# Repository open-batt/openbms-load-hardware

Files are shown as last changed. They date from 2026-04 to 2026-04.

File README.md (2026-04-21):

# OpenBMS Load




**OpenBMS Load** is a hardware design of a resistive load used for battery discharging. Its main purpose is testing the battery management system (BMS) during charge and discharge cycles.

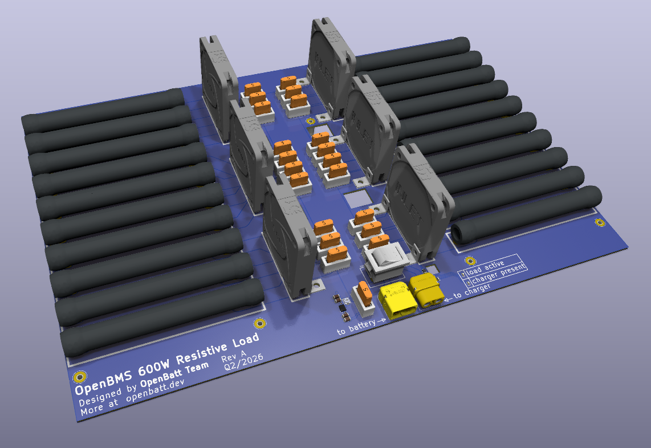
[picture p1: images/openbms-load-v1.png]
OpenBMS v3


## How OpenBMS Load fits into system?

Battery system consists of:

- Li-ion/Li-po battery - your custom 2 to 7-cell battery
- [OpenBMS](https://github.com/open-batt/openbms-hardware)
- Host - I2C/CAN interfaces, wake-up signal, can be a microcontroller, computer, etc.
- Load - your piece of equipment that draws energy from the battery. In this case, we provide OpenBMS-load-hardware, a 600W resistive load for easier BMS development and testing
- Charger - your custom charger, usually a CC/CV charger adjusted to your battery voltage and current

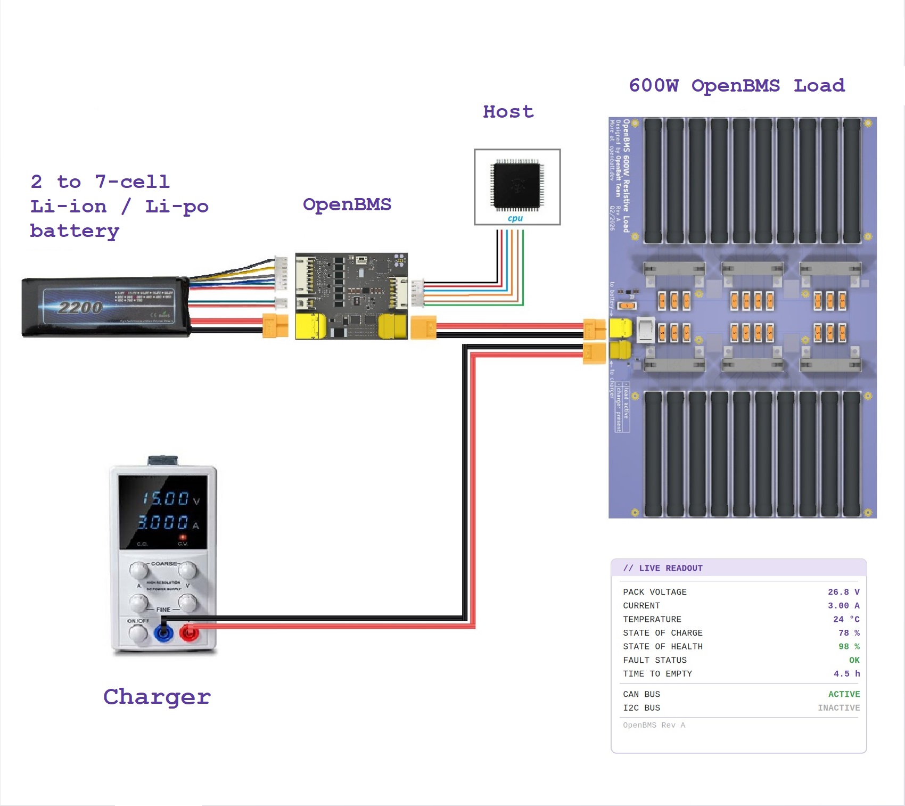
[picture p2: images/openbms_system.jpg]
OpenBMS v3

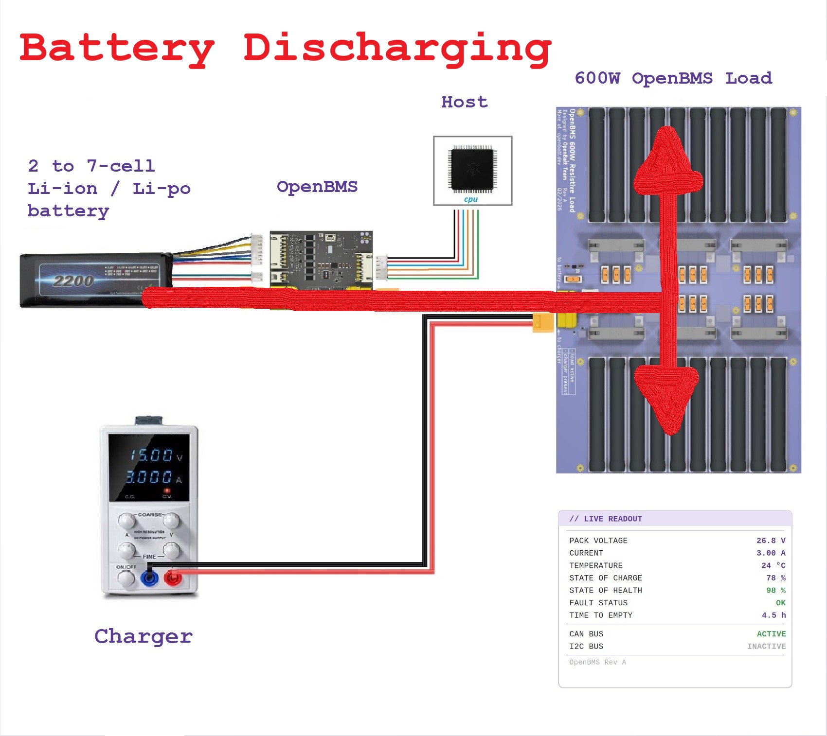
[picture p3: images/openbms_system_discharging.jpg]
OpenBMS v3

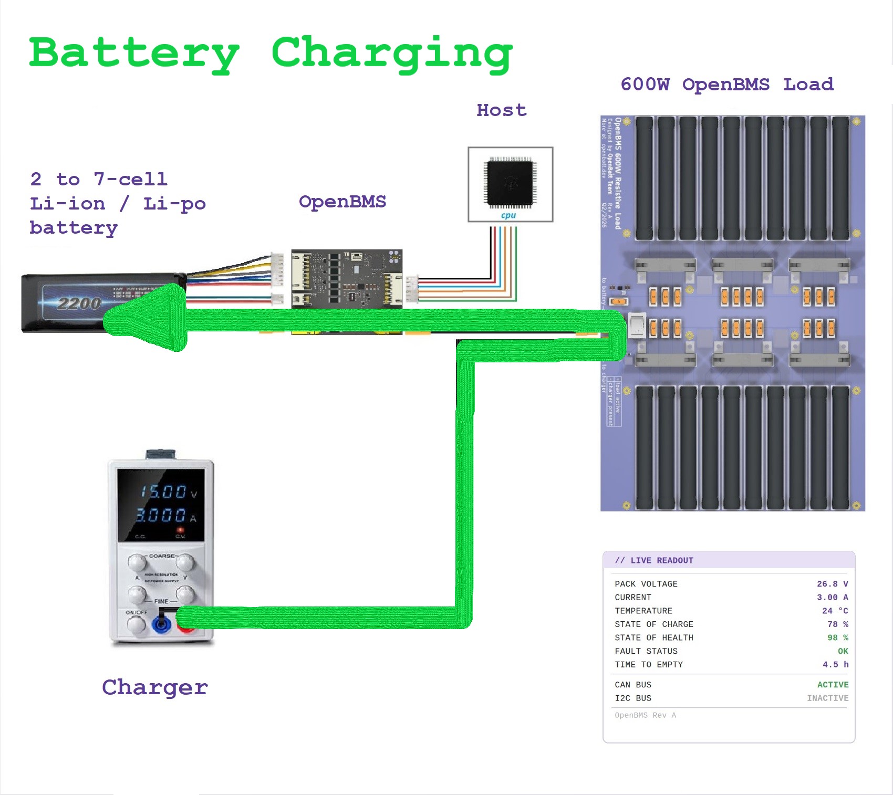
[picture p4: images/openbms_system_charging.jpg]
OpenBMS v3


## Features

- 🔥 Twenty 25-ohm 50W resistors to dissipate up to 600W
- 🔛  Jumpers / 5A fuse - each resistor has jumper/fuse to enable it or disable it - this way total load resistance can be adjusted from 1 to 20 ohms
- 🔌 Male XT60 connector for BMS (battery) connection
- 🔌 Female XT60 connector for charger connection
- 🔄 Tri state switch:
  - 1 - Battery discharging - energy flows from battery to load (resistors)
  - 2 - Battery charging - energy flows from charger to battery (resistors are bypassed and not used)
  - 3 - Idling - battery is neither charging nor discharging
- 💨 Six fans to blow heat from resistors - speed adjustable by potentiometer
- 🟢 Green LED to indicate that charger is present
- 🔴 Red LED to indicate that battery is discharging
  
## Overview

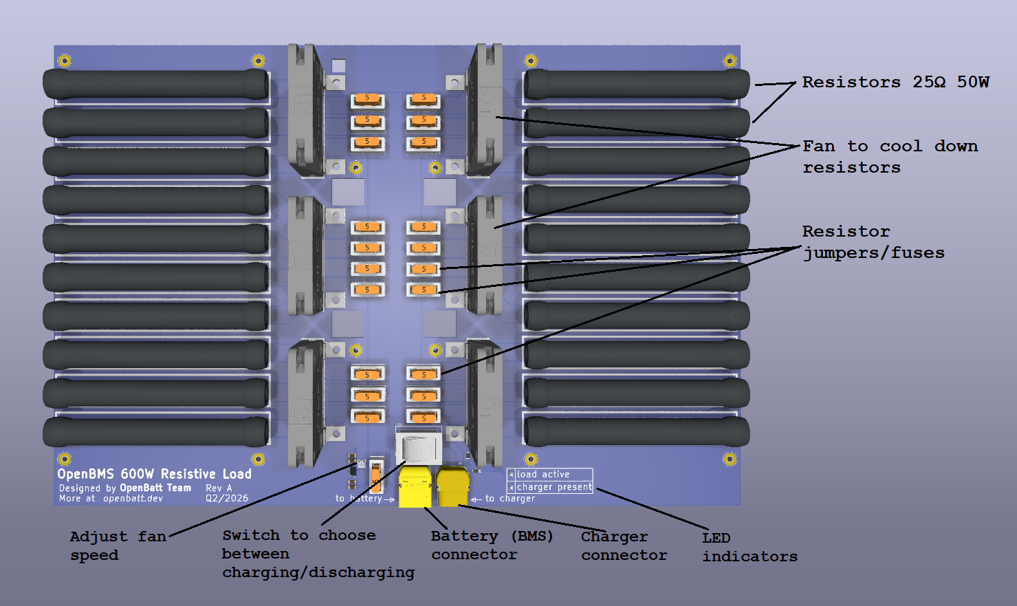
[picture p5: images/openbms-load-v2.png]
OpenBMS v3


The OpenBMS 600W Resistive Load is a purpose-built battery testing board designed to work alongside the OpenBMS system. 

It carries twenty 25Ω 50W wirewound resistors arranged across the board, capable of dissipating up to 600W of power. Each resistor is individually switchable via a jumper and protected by a 5A fuse, allowing the total load resistance to be adjusted between 1 and 20 ohms. 

Six cooling fans keep the resistors from overheating, with speed controlled by an onboard potentiometer. 

Two XT60 connectors handle battery and charger connections, and a three-position switch selects between discharging (energy flows from battery into the resistors), charging (charger feeds the battery directly, bypassing the resistors), and idle mode. 

A green LED signals charger presence and a red LED indicates active discharging.

## ❤️ Funding

This project is funded through [NGI0 Commons Fund](https://nlnet.nl/commonsfund), a fund established by [NLnet](https://nlnet.nl) with financial support from the European Commission's [Next Generation Internet](https://ngi.eu) program. 

[NLnet foundation logo](https://nlnet.nl)
[NGI Zero Logo](https://nlnet.nl/commonsfund)

We are very grateful to the NLnet team for helping us on our path, and we encourage you too to apply and get funds to build your project! 🚀
Learn more at the [NLnet project page](https://nlnet.nl/project/OpenBMS).

## License

OpenBMS-Load is licensed under CERN OHL-S v2 license.

Check [openbatt.dev](https://openbatt.dev) for more!

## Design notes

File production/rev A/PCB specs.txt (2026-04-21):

Layers: 2
PCB thickness: 1.6mm
Min hole size: 0.3mm
Surface finish:  HASL lead free
Min track/spacing:  6/6mil
Solder mask: purple
Silkscreen: white
Finished copper:  1 oz Cu

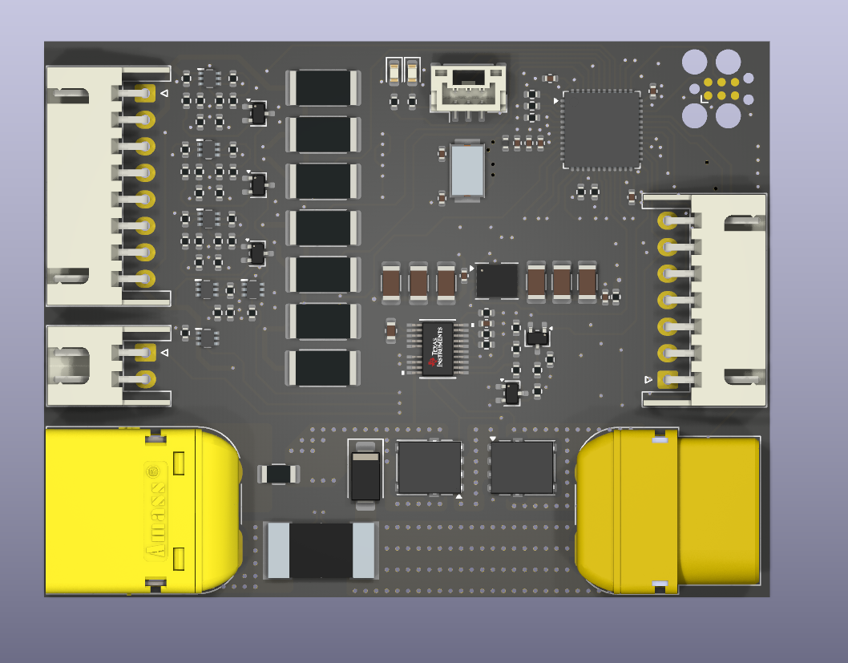
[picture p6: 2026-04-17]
images/openbms-v1.png

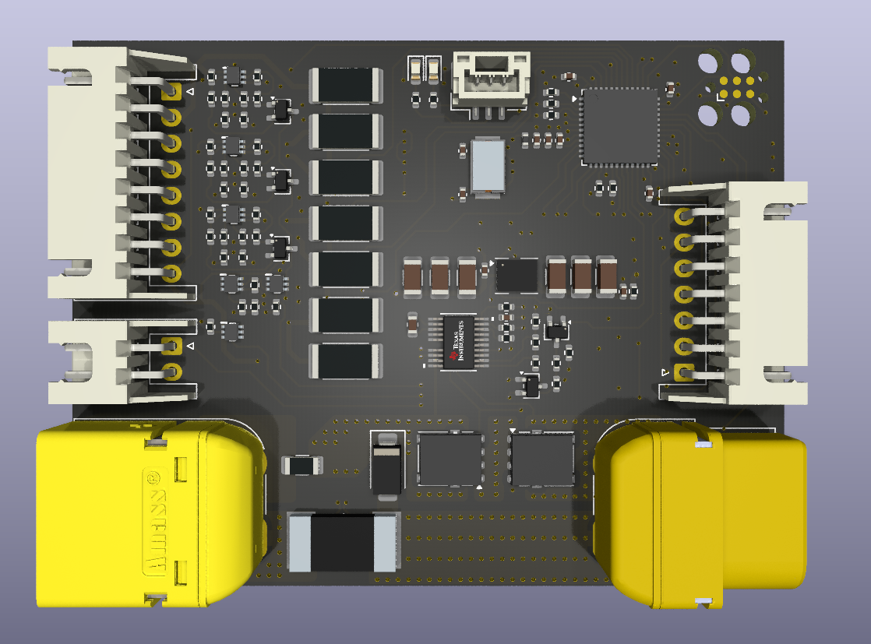
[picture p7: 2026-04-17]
images/openbms-v2.png

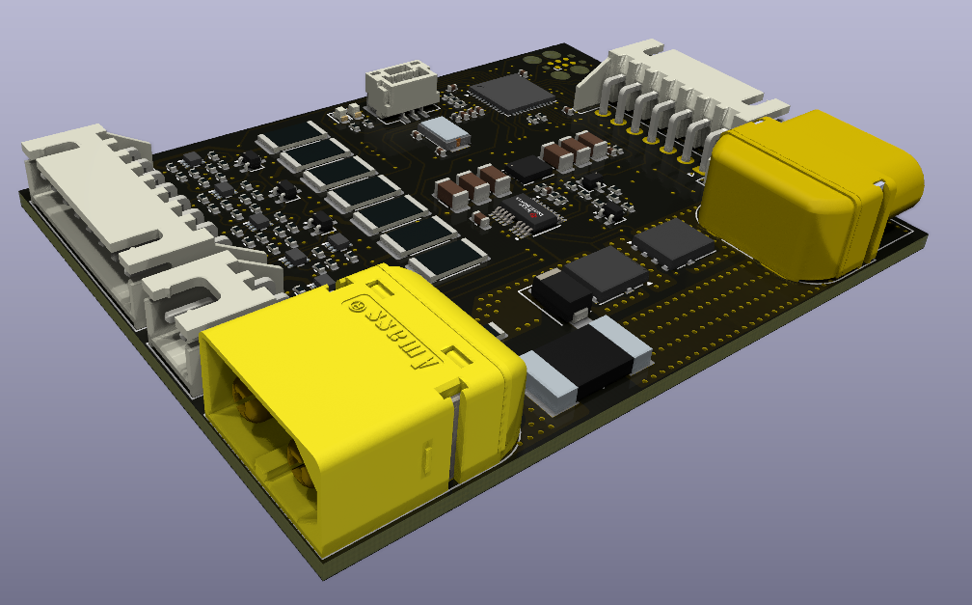
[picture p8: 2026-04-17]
images/openbms-v3.png

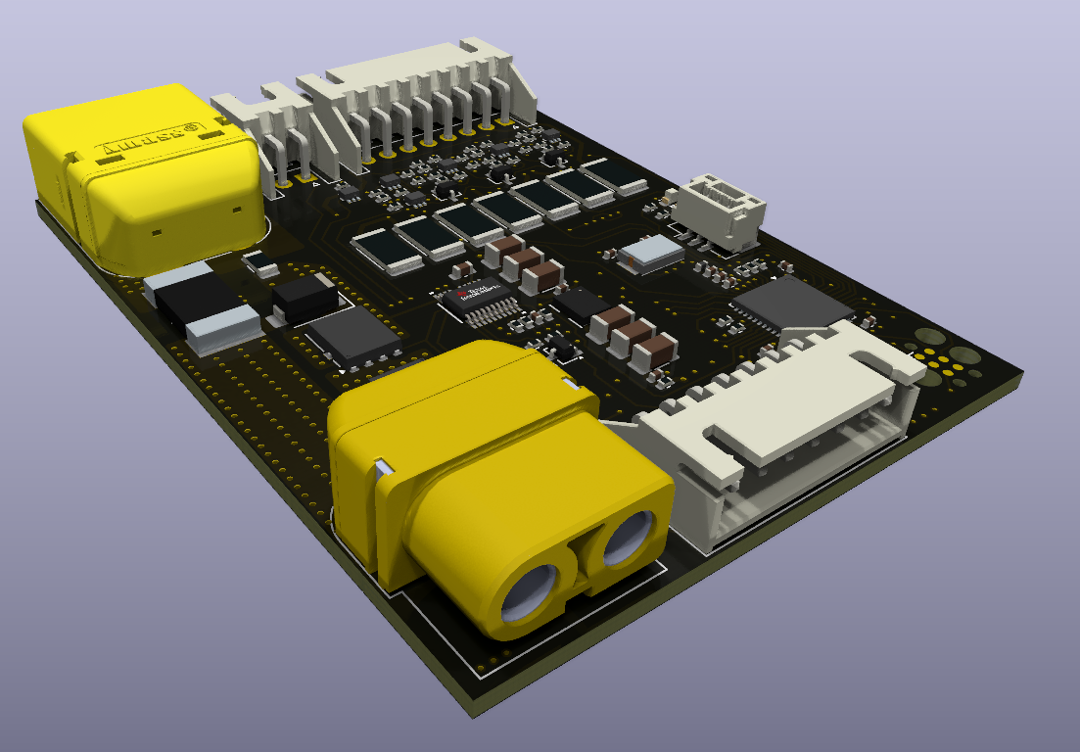
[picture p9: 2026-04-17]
images/openbms-v5.png

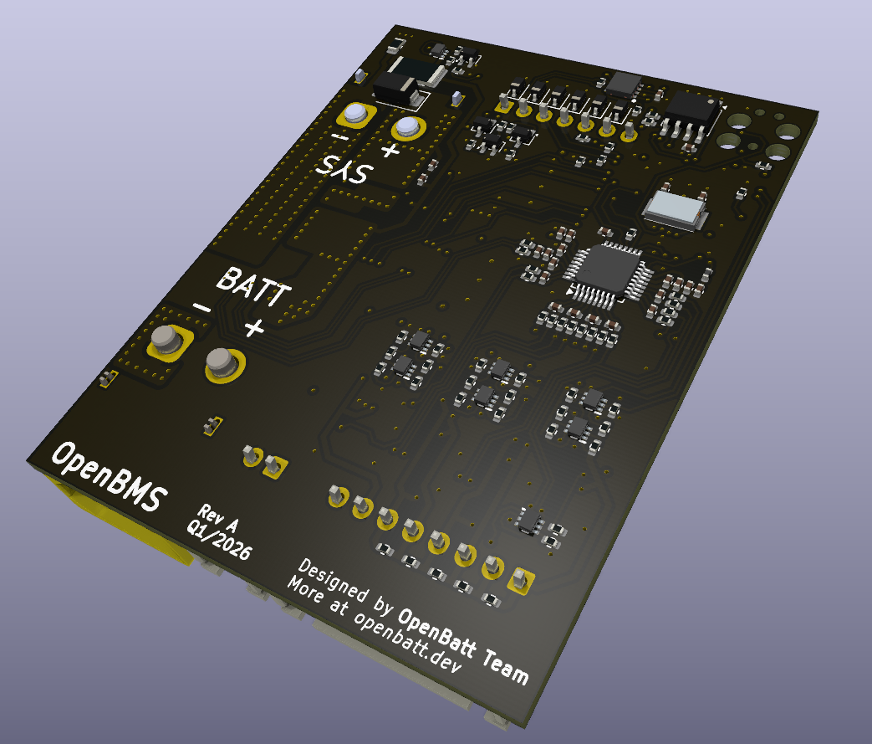
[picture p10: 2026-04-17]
images/openbms-v4.png

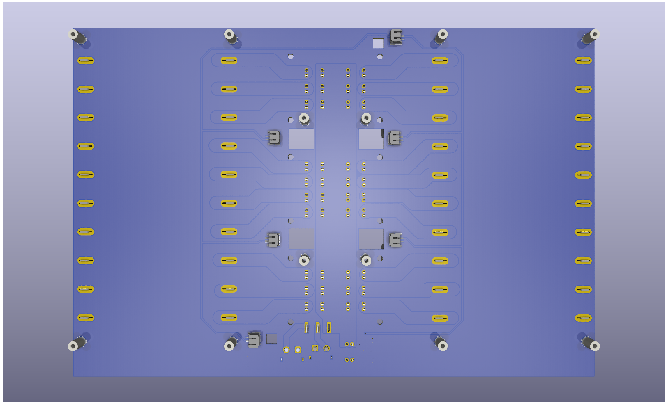
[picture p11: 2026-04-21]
production/rev A/openbms-load-img-3.png

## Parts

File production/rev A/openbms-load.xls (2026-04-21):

Reference | Qty | Value | Package | Manufacturer_Part_Number
B1,B2,B3,B4,B5,B6,B7,B8,B9,B10,B11,B12 | 12 | L mounting bracket | L bracket | 633
C1,C2,C4,C5 | 4 | 10u | 1206 | CL31A106MBHNNNE
C3,C6 | 2 | 100n | 0402 | GRM155R71A104KA01D
D1 | 1 | Green LED | 0603 | LTST-S270KGKT
D2 | 1 | Red LED | 0603 | LTST-C190KRKT
D3,D4 | 2 | LED driver | PowerDIâ 123 | AL5809-15P1-7
F1,F2,F3,F4,F5,F6,F7,F8,F9,F10,F11,F12,F13,F14,F15,F16,F17,F18,F19,F20,F21 | 21 | Fuse housing | 11x3.85mm | 3568
H1,H2,H3,H4,H5,H6,H7,H8,H9,H10,H11,H12 | 12 | Standoff M3 10mm | M3 10mm | 24433
J1,J2,J3,J4,J5,J6,J7,J8,J9,J10,J11,J12,J13,J14,J15,J16,J17,J18,J19,J20,J21 | 21 | 5A Fuse | 11x5mm | 0297005.WXNV
M1,M2,M3,M4,M5,M6 | 6 | Fan 50mm | 50x50x10mm | MF50101V1-1000U-A99
P1,P2,P3,P4,P5,P6 | 6 | JST connector | JST 02 connector | S2B-PH-SM4-TB
P7 | 1 | XT60PW-M connector | XT60PW-M connector | XT60PW-M
P8 | 1 | XT60PW-F connector | XT60PW-F connector | XT60PW-F
POT1 | 1 | 10k pot | 3.8x3.6mm | TC33X-2-103E
R1,R2,R3,R4,R5,R6,R7,R8,R9,R10,R11,R12,R13,R14,R15,R16,R17,R18,R19,R20 | 20 | 25R 50W | 102x15 | L50J25RE
SW1 | 1 | Switch | 19.2x12.9mm | VRS-3-Q3PSI-19KNN-0-M2
U1 | 1 | LMZM23600SILR | 3.8 x 3 | LMZM23600SILR

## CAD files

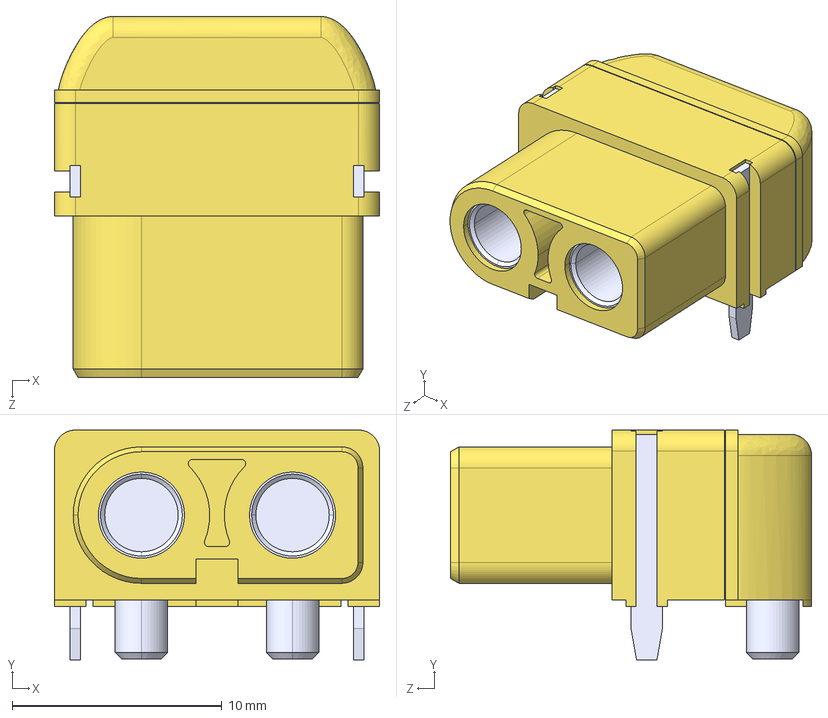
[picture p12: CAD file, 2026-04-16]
openbms-load/3D models/XT60PW-F.stp
15.5 x 11.0 x 17.2 mm

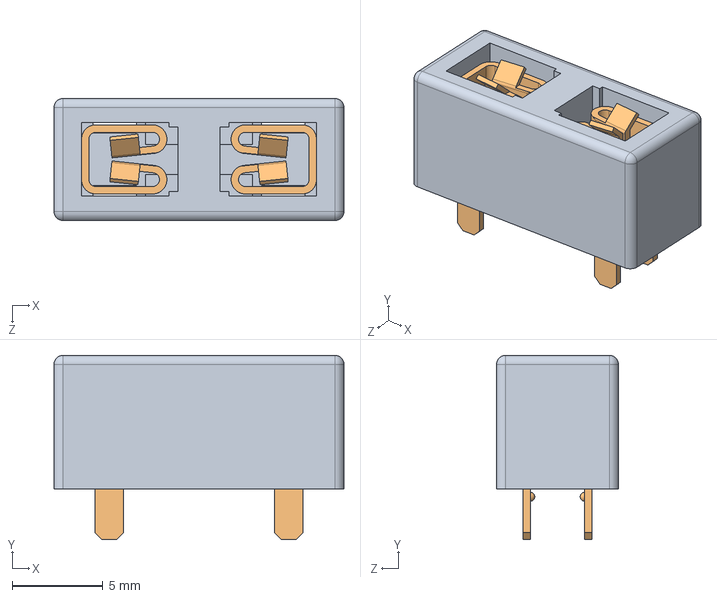
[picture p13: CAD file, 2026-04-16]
openbms-load/3D models/3568.stp
16.0 x 10.2 x 6.73 mm

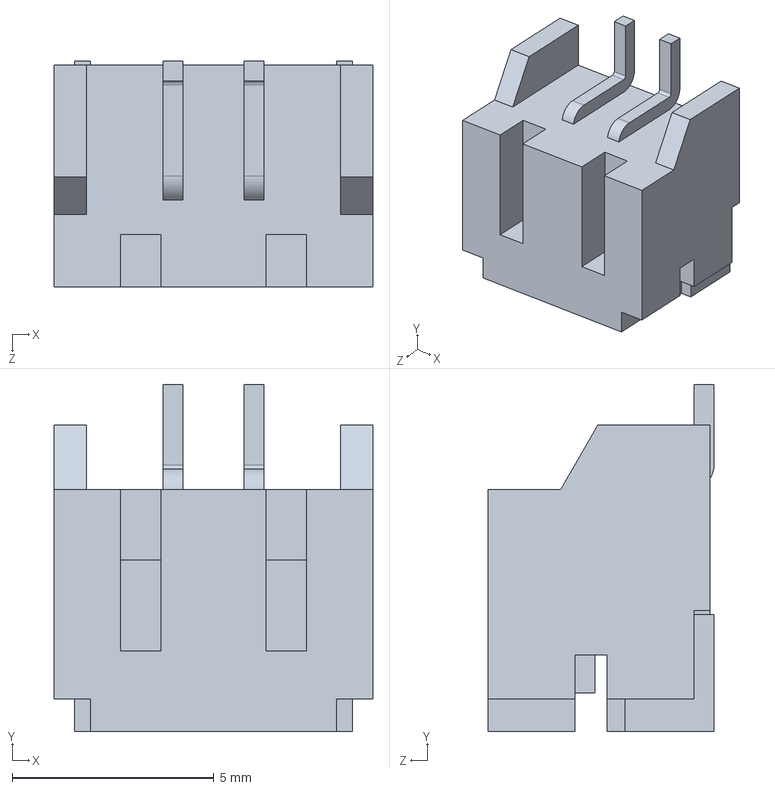
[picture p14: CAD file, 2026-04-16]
openbms-load/3D models/S2B-PH-SM4-TB_LF__SN_.stp
7.90 x 8.60 x 5.60 mm

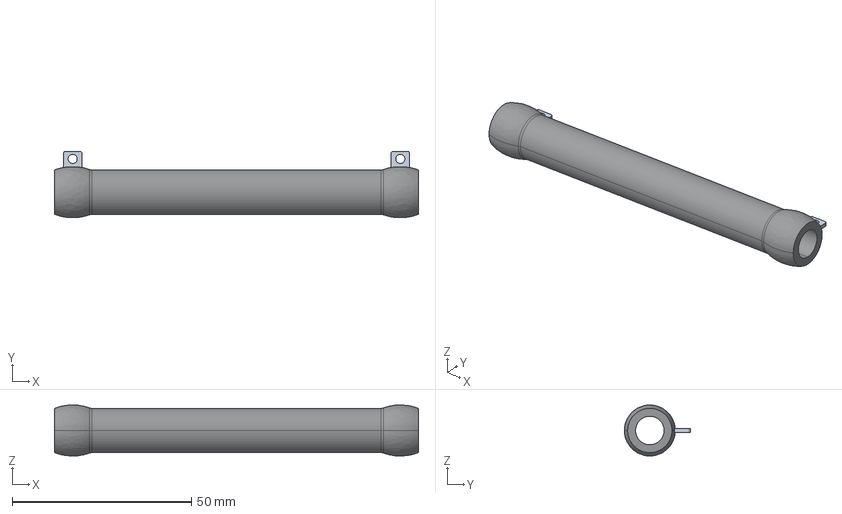
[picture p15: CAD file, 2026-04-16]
openbms-load/3D models/L50J25RE.stp
101.6 x 18.6 x 14.2 mm

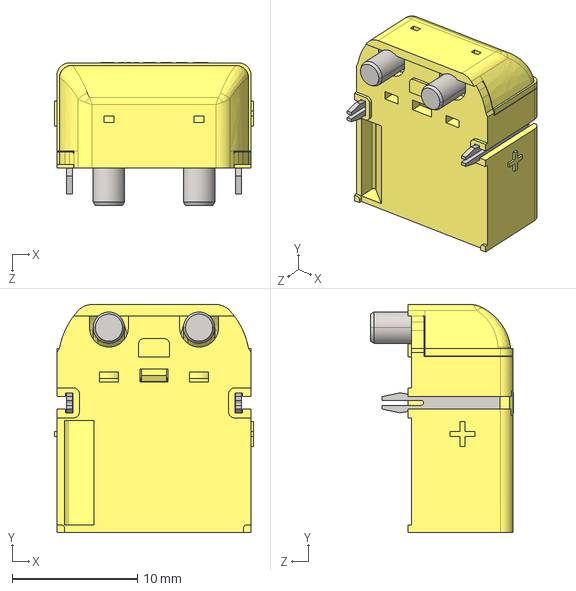
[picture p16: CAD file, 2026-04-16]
openbms-load/3D models/XT60PW-M.stp
15.9 x 18.2 x 11.5 mm

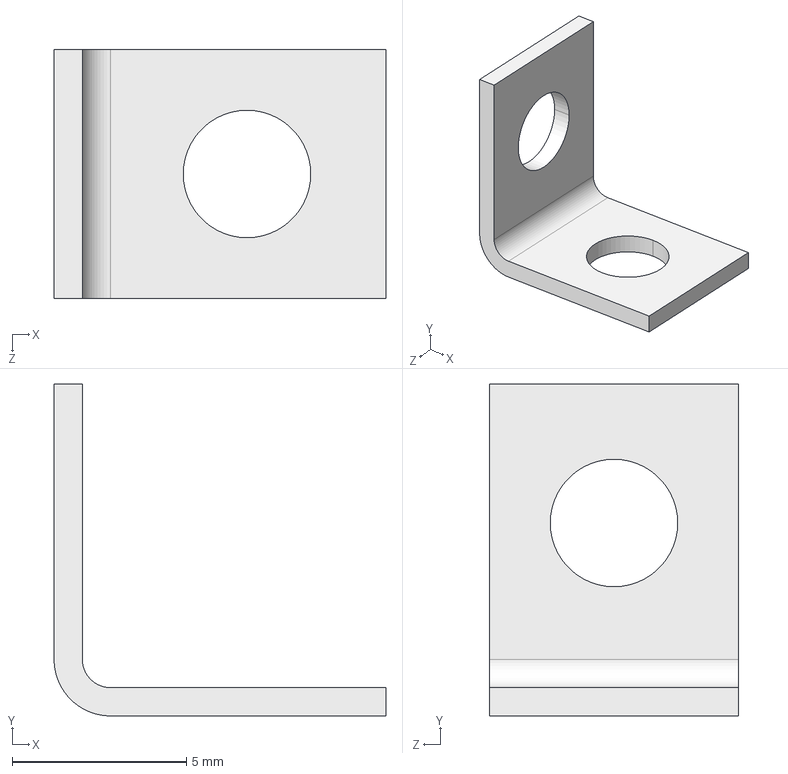
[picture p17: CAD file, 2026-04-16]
openbms-load/3D models/633.stp
9.53 x 9.53 x 7.14 mm

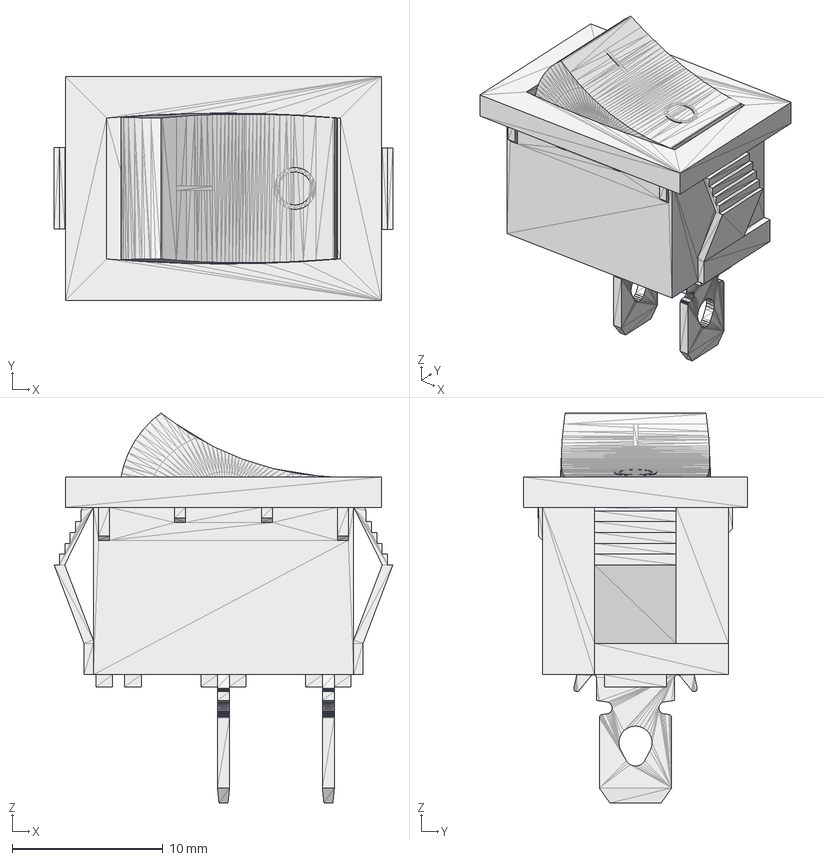
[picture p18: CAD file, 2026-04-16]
openbms-load/3D models/VRS-3-Q3PSI-19KNN-0-M2.step
22.5 x 14.8 x 25.8 mm

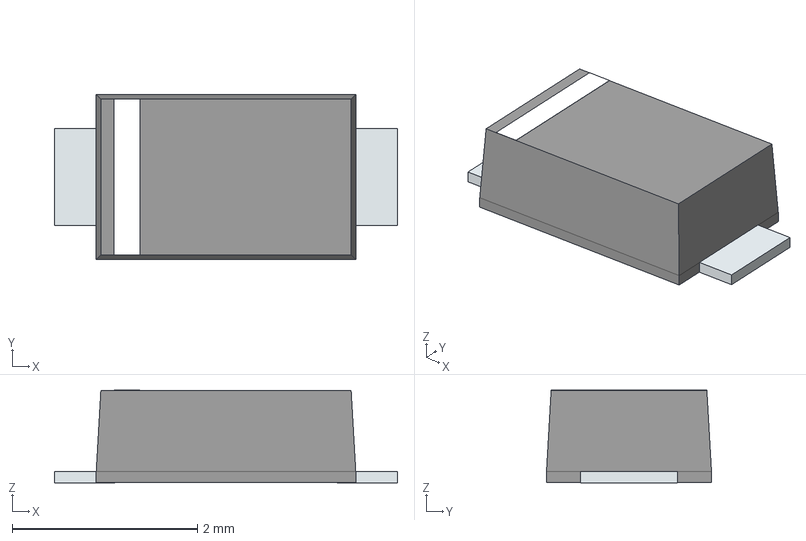
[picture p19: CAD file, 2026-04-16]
openbms-load/3D models/AL5809-15P1-7.stp
3.70 x 1.78 x 1.00 mm
PinKIdent
PinK
PinA

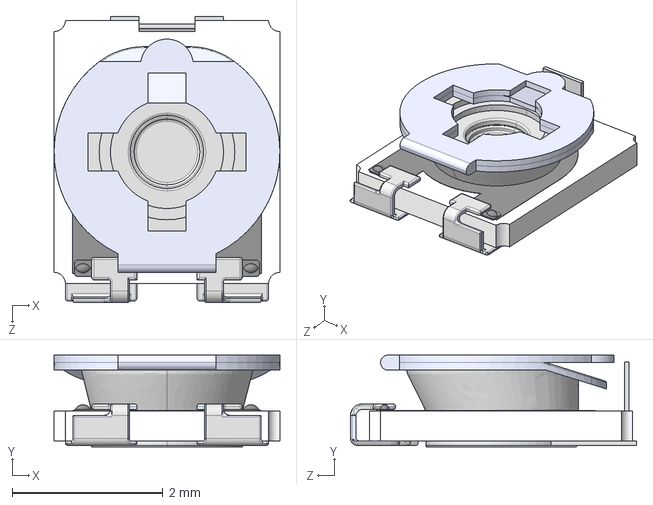
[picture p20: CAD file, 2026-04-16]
openbms-load/3D models/TC33X-2-103E.stp
3.00 x 1.22 x 3.80 mm

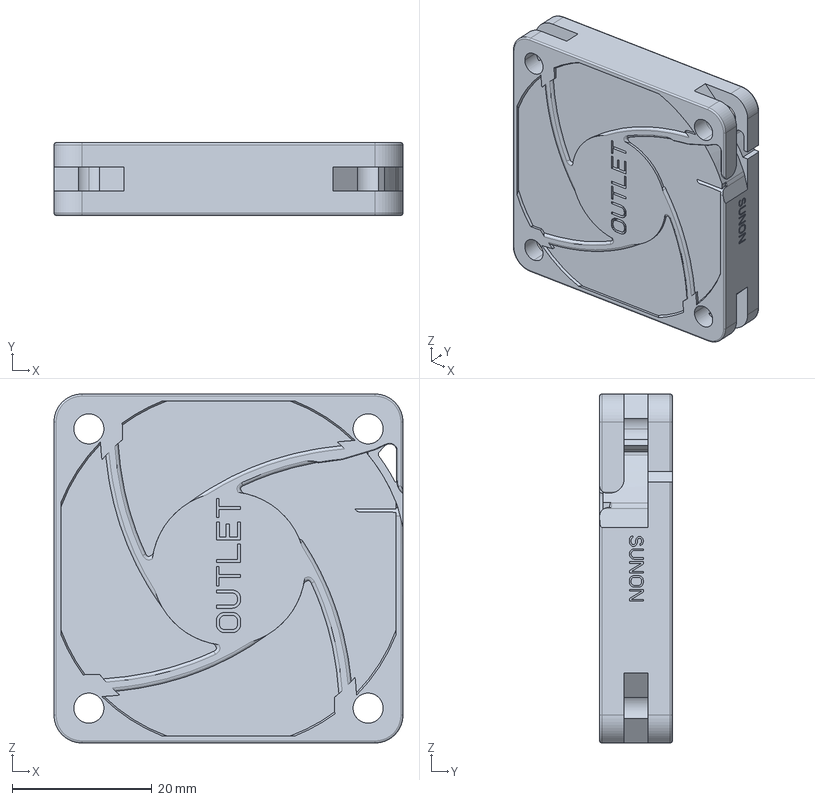
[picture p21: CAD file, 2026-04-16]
openbms-load/3D models/MF50101V1-1000U-A99.stp
50.0 x 10.4 x 50.0 mm

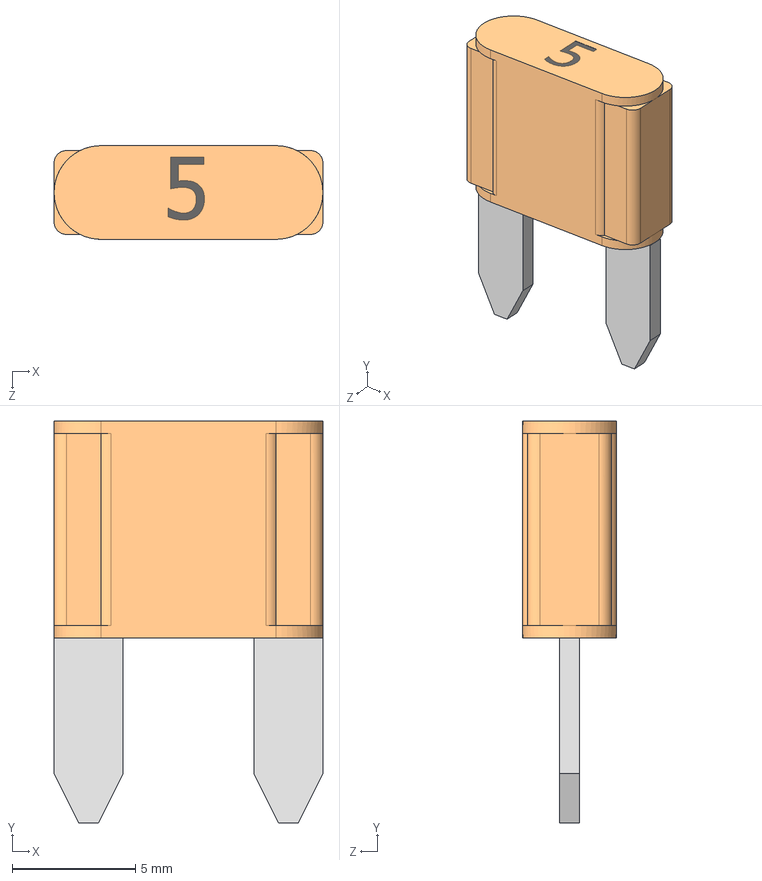
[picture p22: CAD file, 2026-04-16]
openbms-load/3D models/0297005.WXNV.stp
10.9 x 16.3 x 3.80 mm
Part8fgfgfg
edeedqq
edeedqq_MIR

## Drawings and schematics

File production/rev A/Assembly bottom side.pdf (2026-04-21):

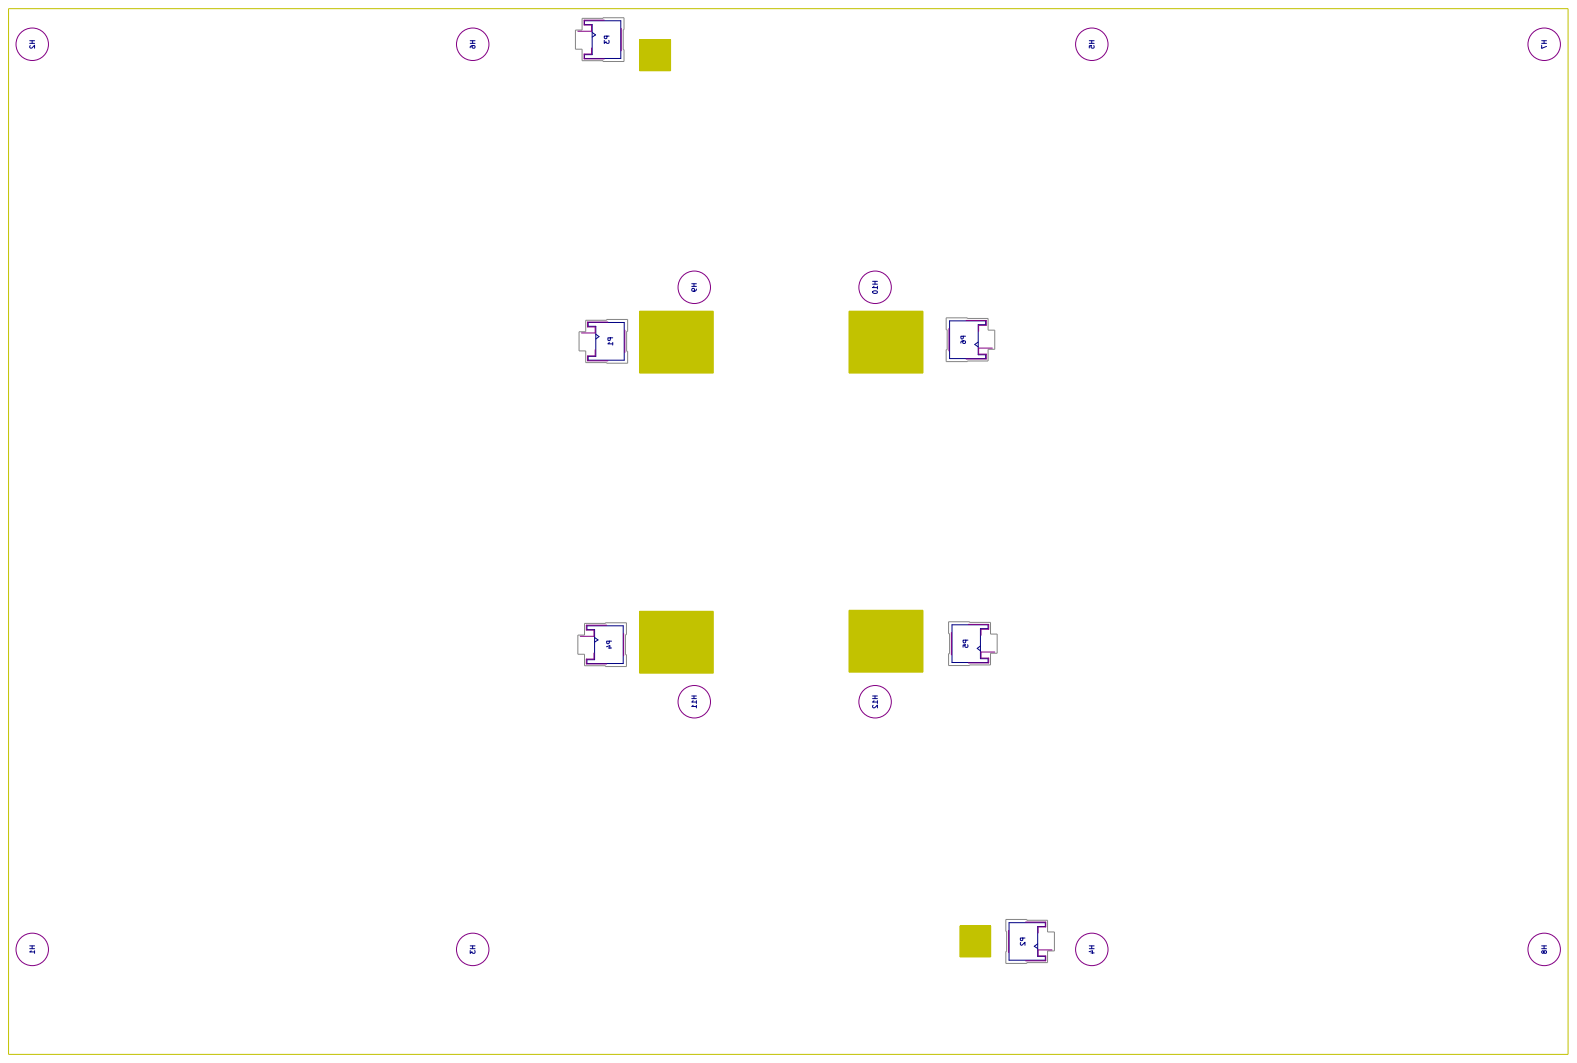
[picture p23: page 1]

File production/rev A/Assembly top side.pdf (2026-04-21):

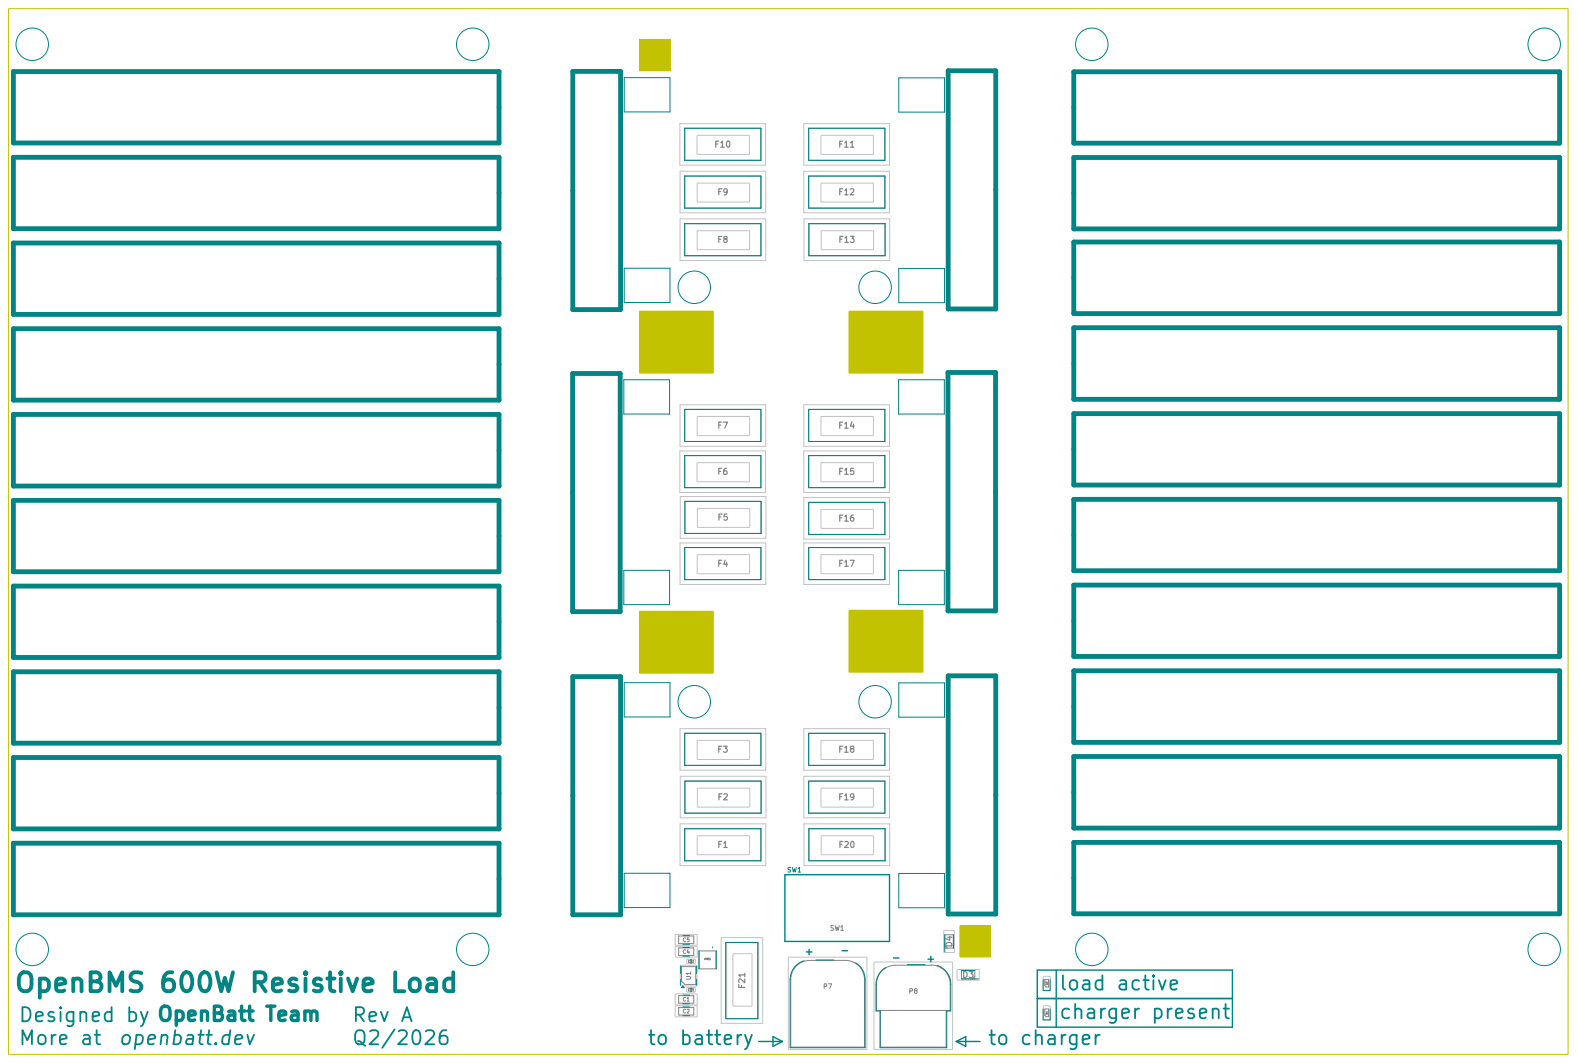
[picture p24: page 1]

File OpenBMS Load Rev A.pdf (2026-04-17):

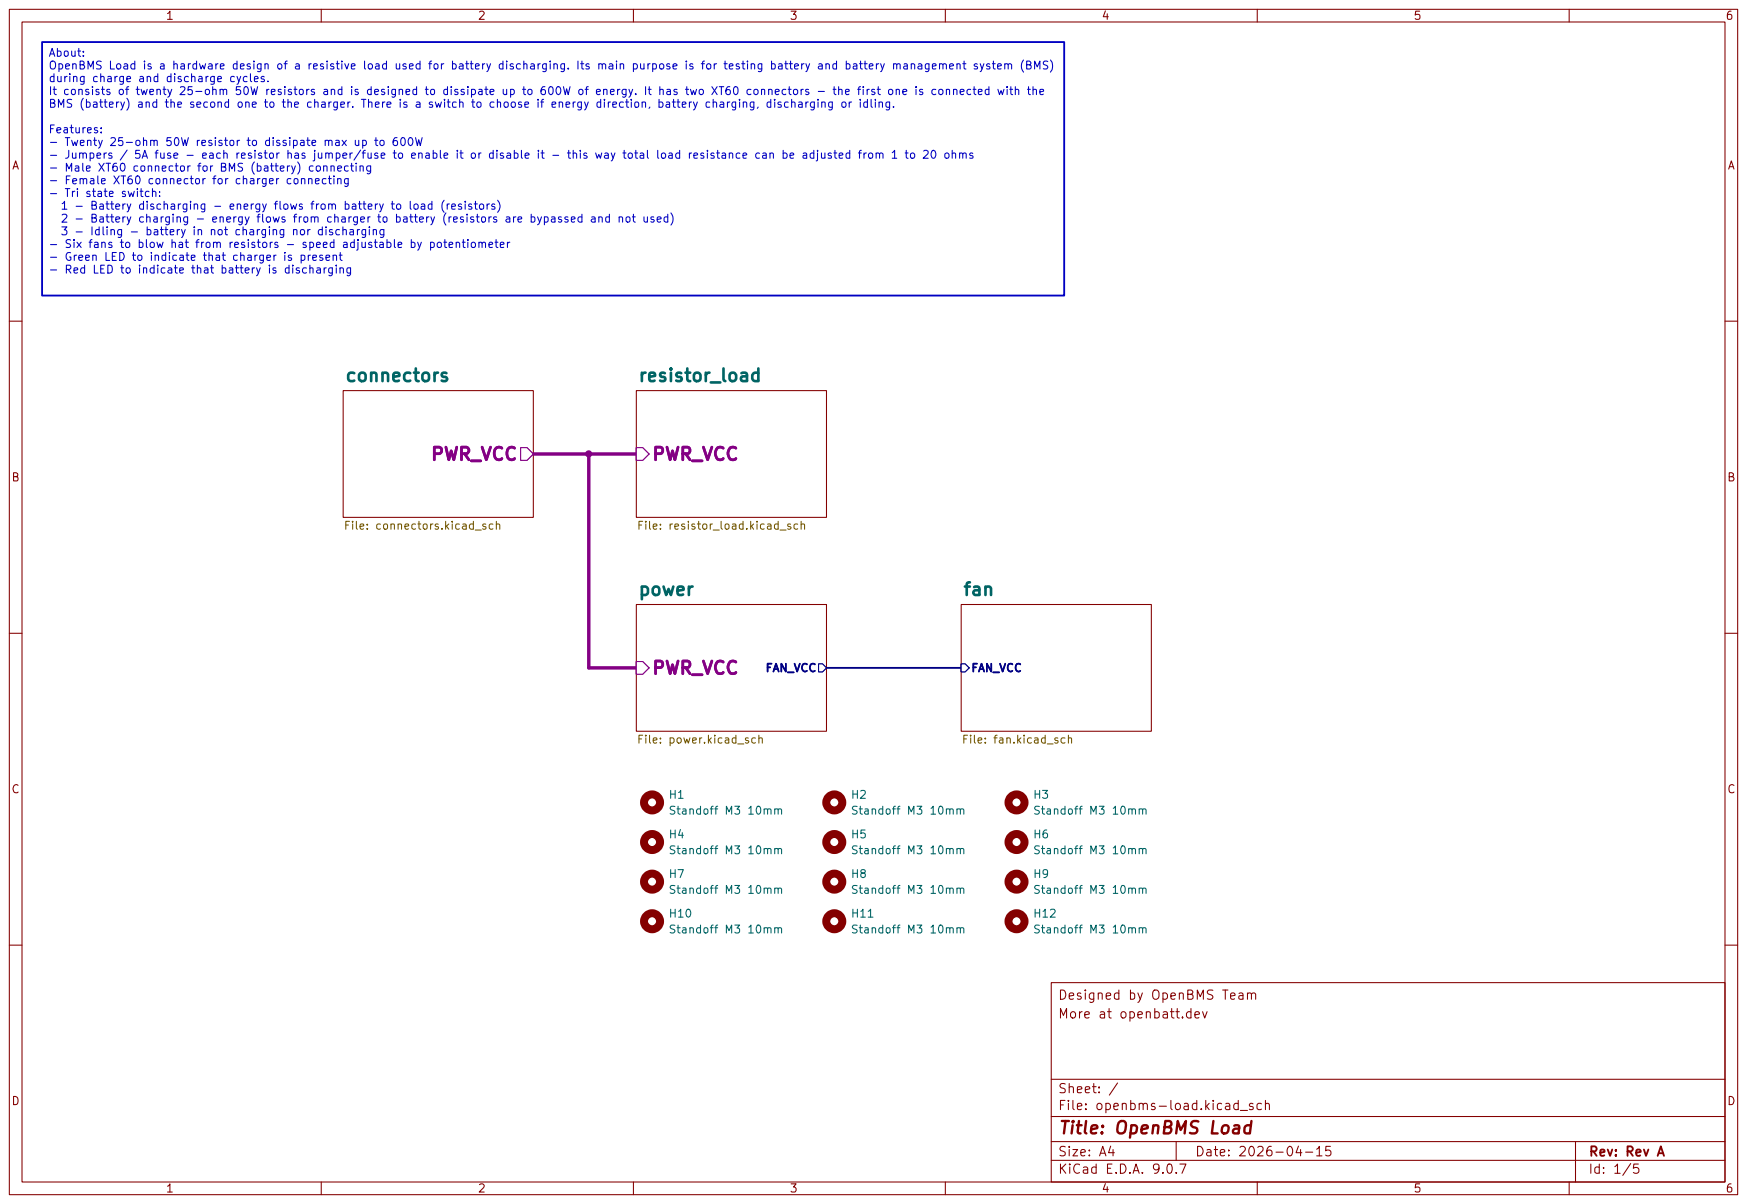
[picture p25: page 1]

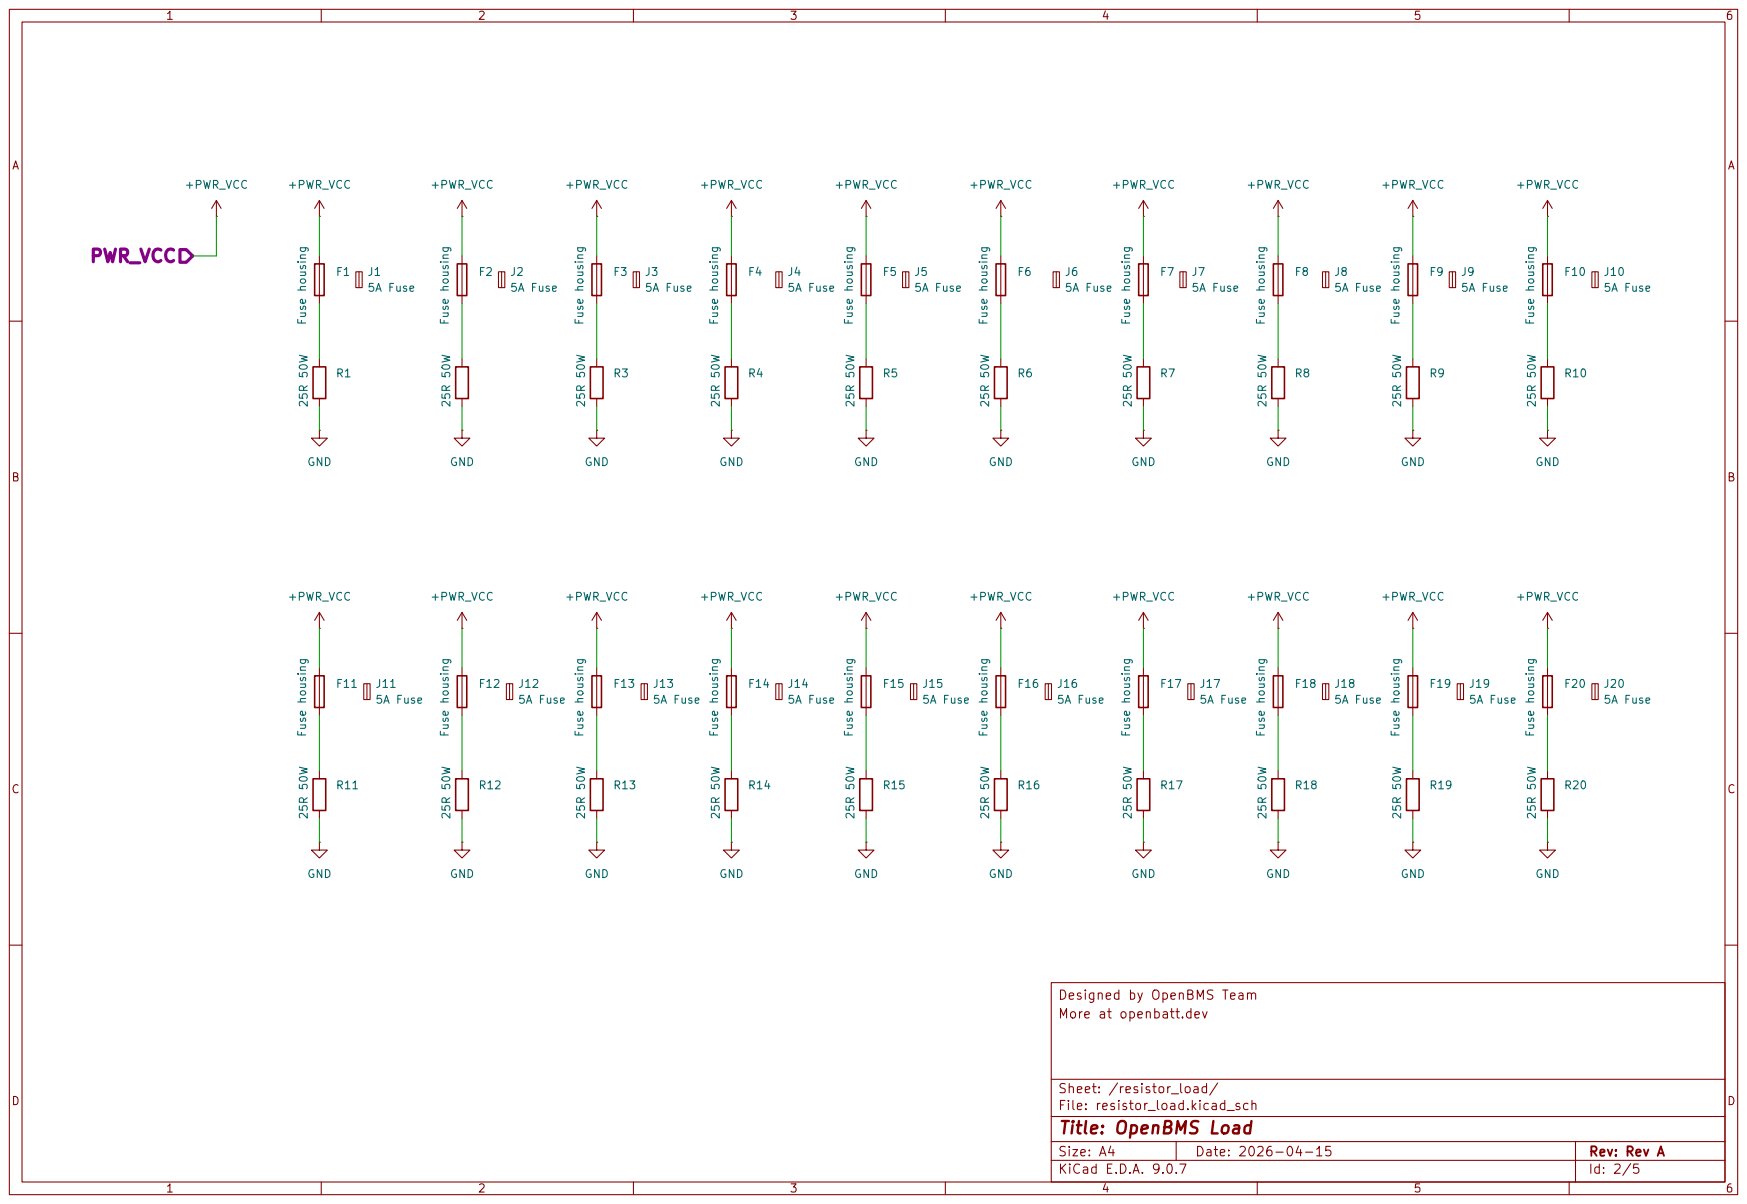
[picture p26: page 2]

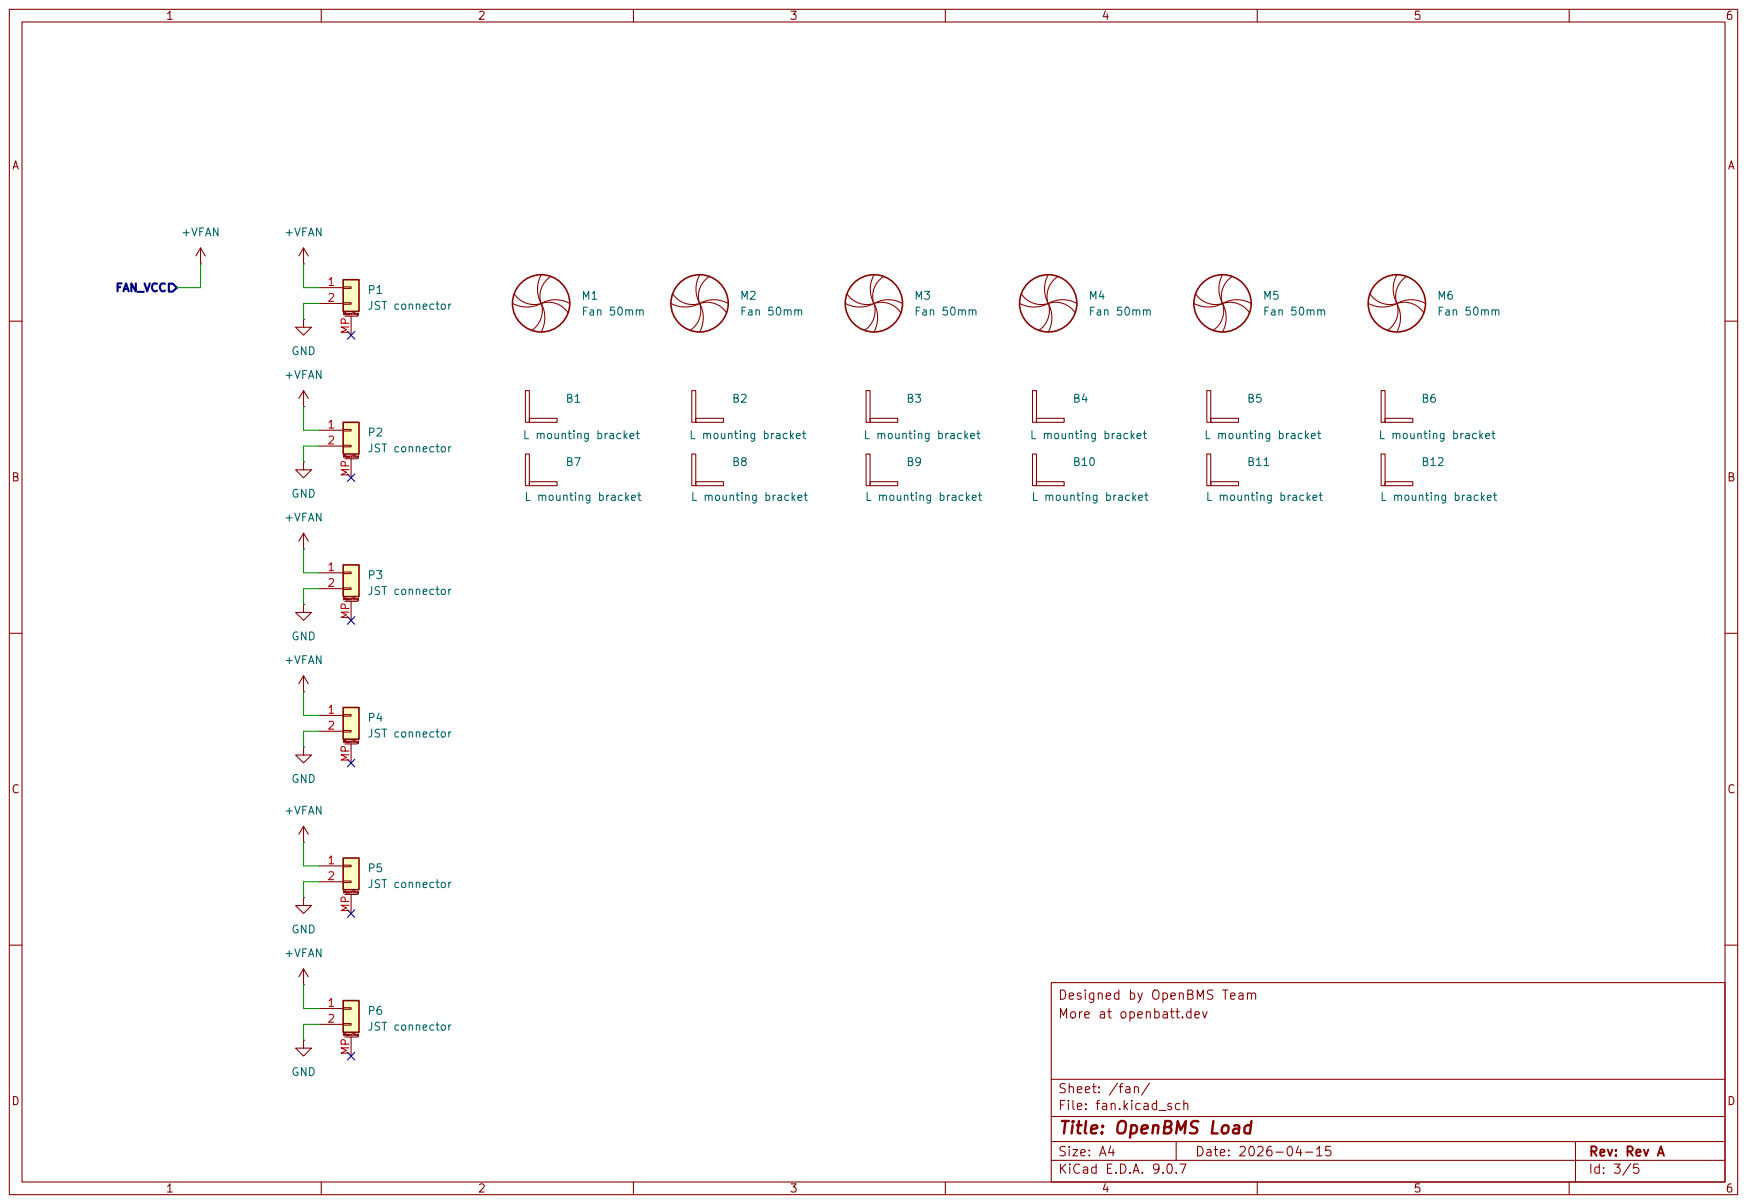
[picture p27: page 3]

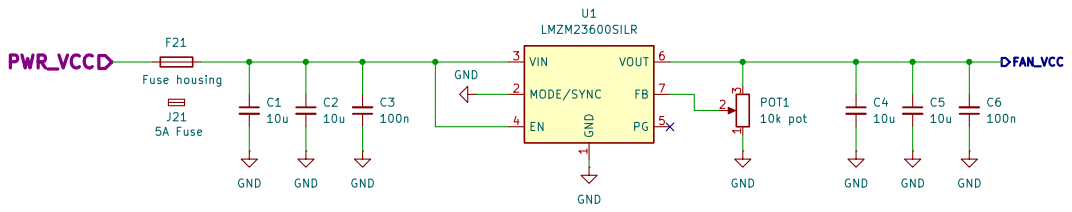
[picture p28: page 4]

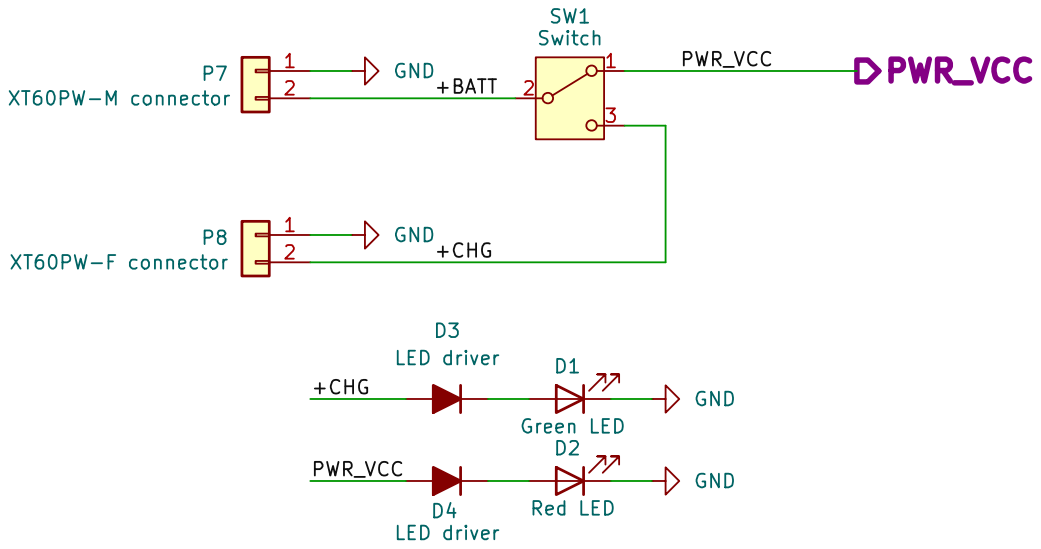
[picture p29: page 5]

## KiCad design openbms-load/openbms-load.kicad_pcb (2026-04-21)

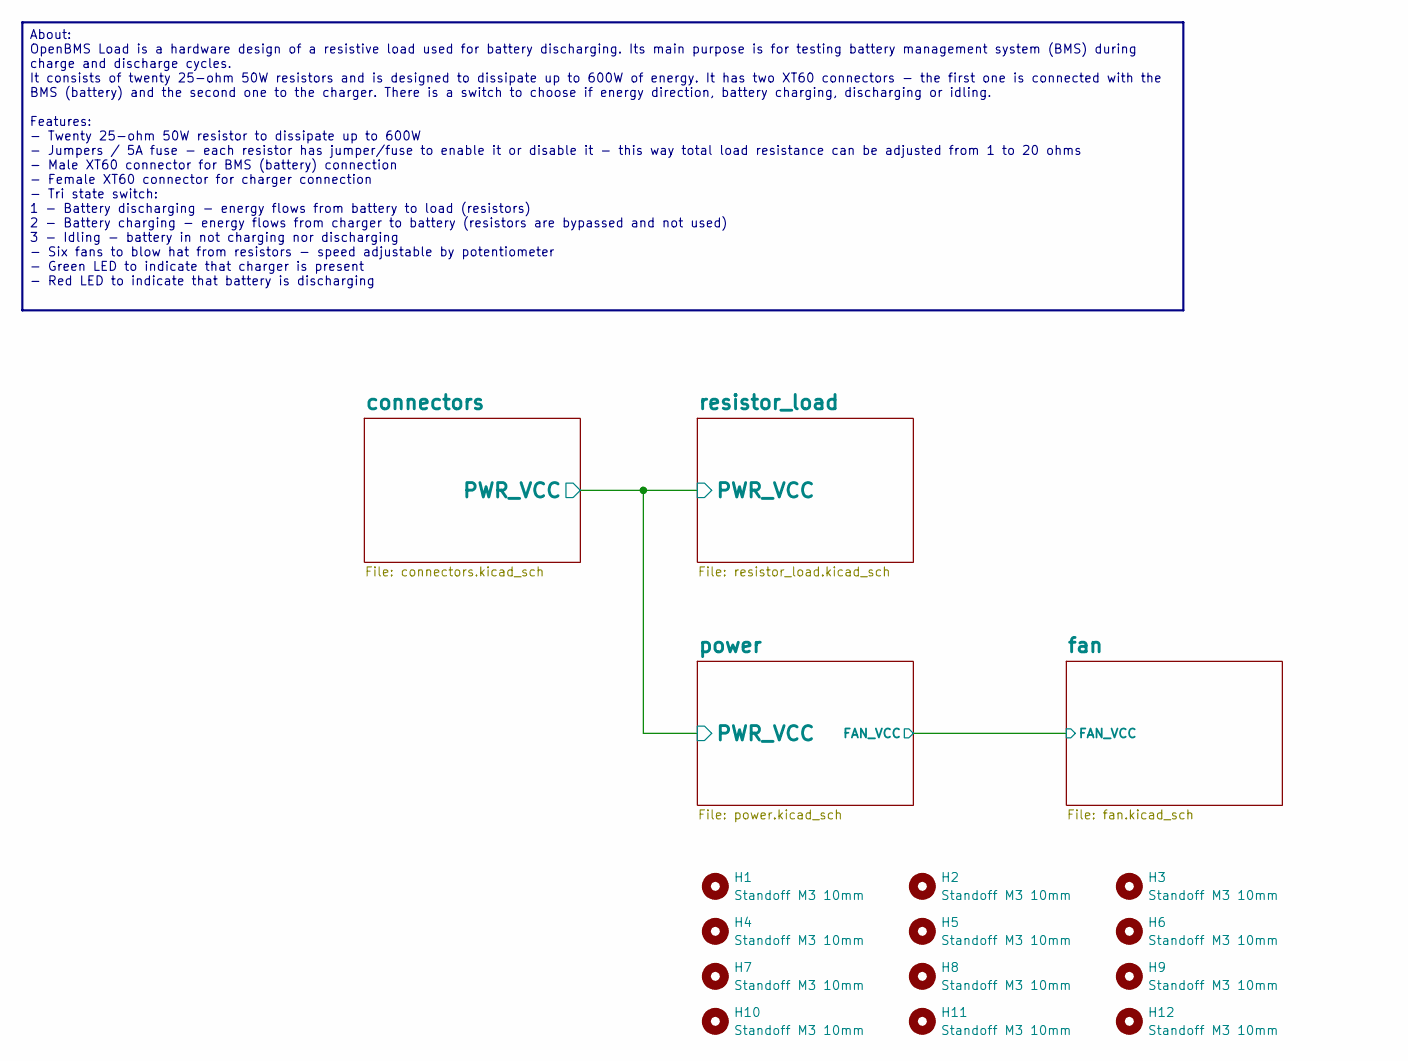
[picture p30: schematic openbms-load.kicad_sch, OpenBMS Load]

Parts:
H1, H2, H3, H4, H5, H6, H7, H8, H9, H10, H11, H12: Standoff M3 10mm; 24433; Manufacturer_Part_Number 24433

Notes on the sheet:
About: OpenBMS Load is a hardware design of a resistive load used for battery discharging. Its main purpose is for testing battery management system (BMS) during charge and discharge cycles. It consists of twenty 25-ohm 50W resistors and is designed to dissipate up to 600W of energy. It has two XT6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

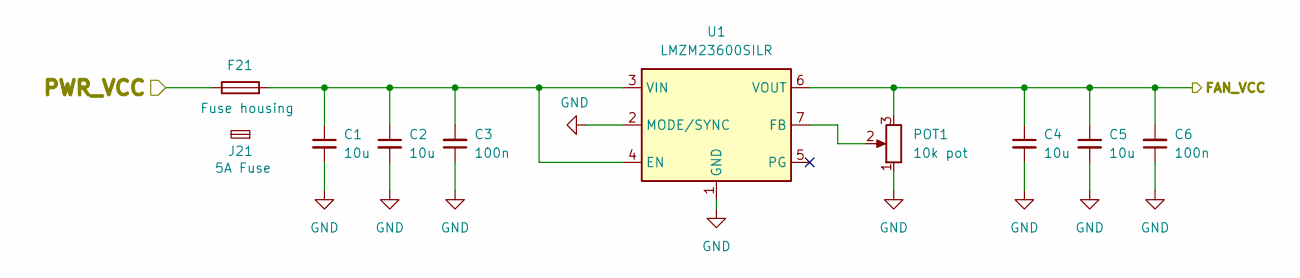
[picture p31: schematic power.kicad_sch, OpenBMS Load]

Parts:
C1, C2, C4, C5: 10u; C_1206_3216Metric; Manufacturer_Part_Number CL31A106MBHNNNE
C3, C6: 100n; C_0402_1005Metric; Manufacturer_Part_Number GRM155R71A104KA01D
F21: Fuse housing; 3568; Manufacturer_Part_Number 3568
J21: 5A Fuse; 0297005.WXNV; Manufacturer_Part_Number 0297005.WXNV
POT1: 10k pot; TC33X2503E; Manufacturer_Part_Number TC33X-2-103E
U1: LMZM23600SILR; Manufacturer_Part_Number LMZM23600SILR

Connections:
+PWR_VCC: F21.1; also elsewhere on the board
+VFAN: C4.1, C5.1, C6.2, POT1.3, U1.6 (VOUT); also elsewhere on the board
GND: C1.2, C2.2, C3.1, C4.2, C5.2, C6.1, POT1.1, U1.1 (GND), U1.2 (MODE/SYNC), U1.11 (GND); also elsewhere on the board
unnamed: C1.1, C2.1, C3.2, F21.2, U1.3 (VIN), U1.4 (EN)
unnamed: POT1.2, U1.7 (FB)

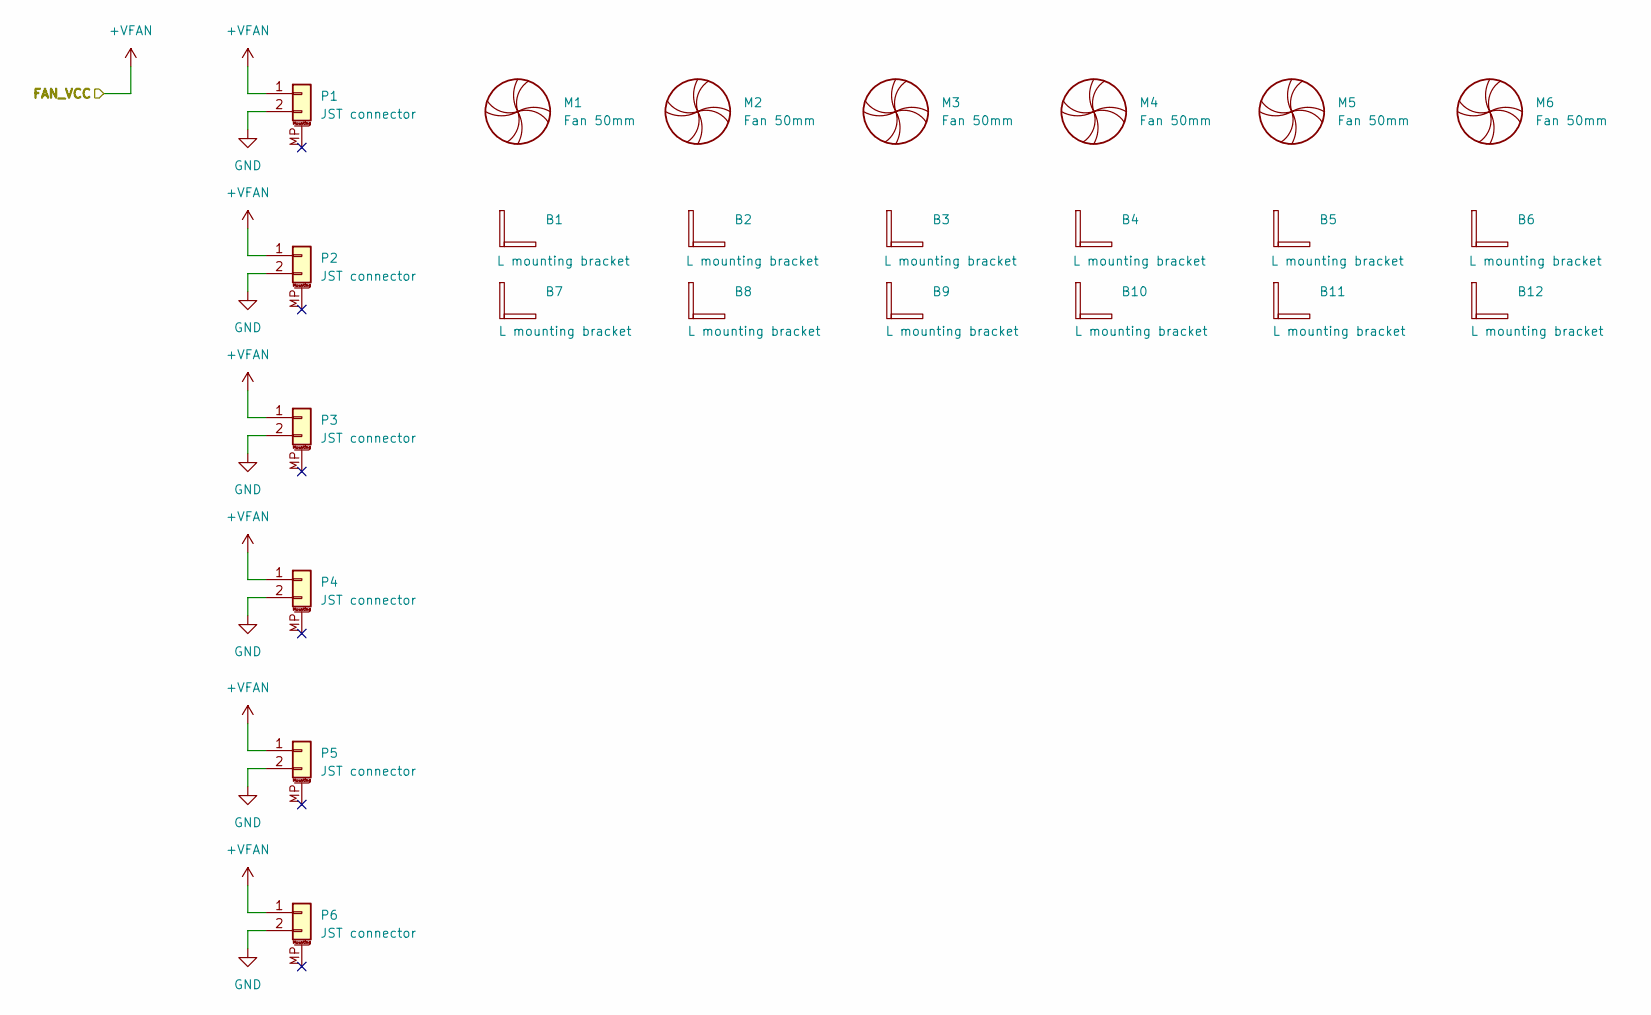
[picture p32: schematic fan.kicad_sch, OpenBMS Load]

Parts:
B1, B2, B3, B4, B5, B6, B7, B8, B9, B10, B11, B12: L mounting bracket; 633; Manufacturer_Part_Number 633
M1, M2, M3, M4, M5, M6: Fan 50mm; fan_MF50101V1-1000U-A99; Manufacturer_Part_Number MF50101V1-1000U-A99
P1, P2, P3, P4, P5, P6: JST connector; JST_PH_S2B-PH-SM4-TB_1x02-1MP_P2.00mm_Horizontal; Manufacturer_Part_Number S2B-PH-SM4-TB

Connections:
+VFAN: P1.1, P2.1, P3.1, P4.1, P5.1, P6.1; also elsewhere on the board
GND: P1.2, P2.2, P3.2, P4.2, P5.2, P6.2; also elsewhere on the board

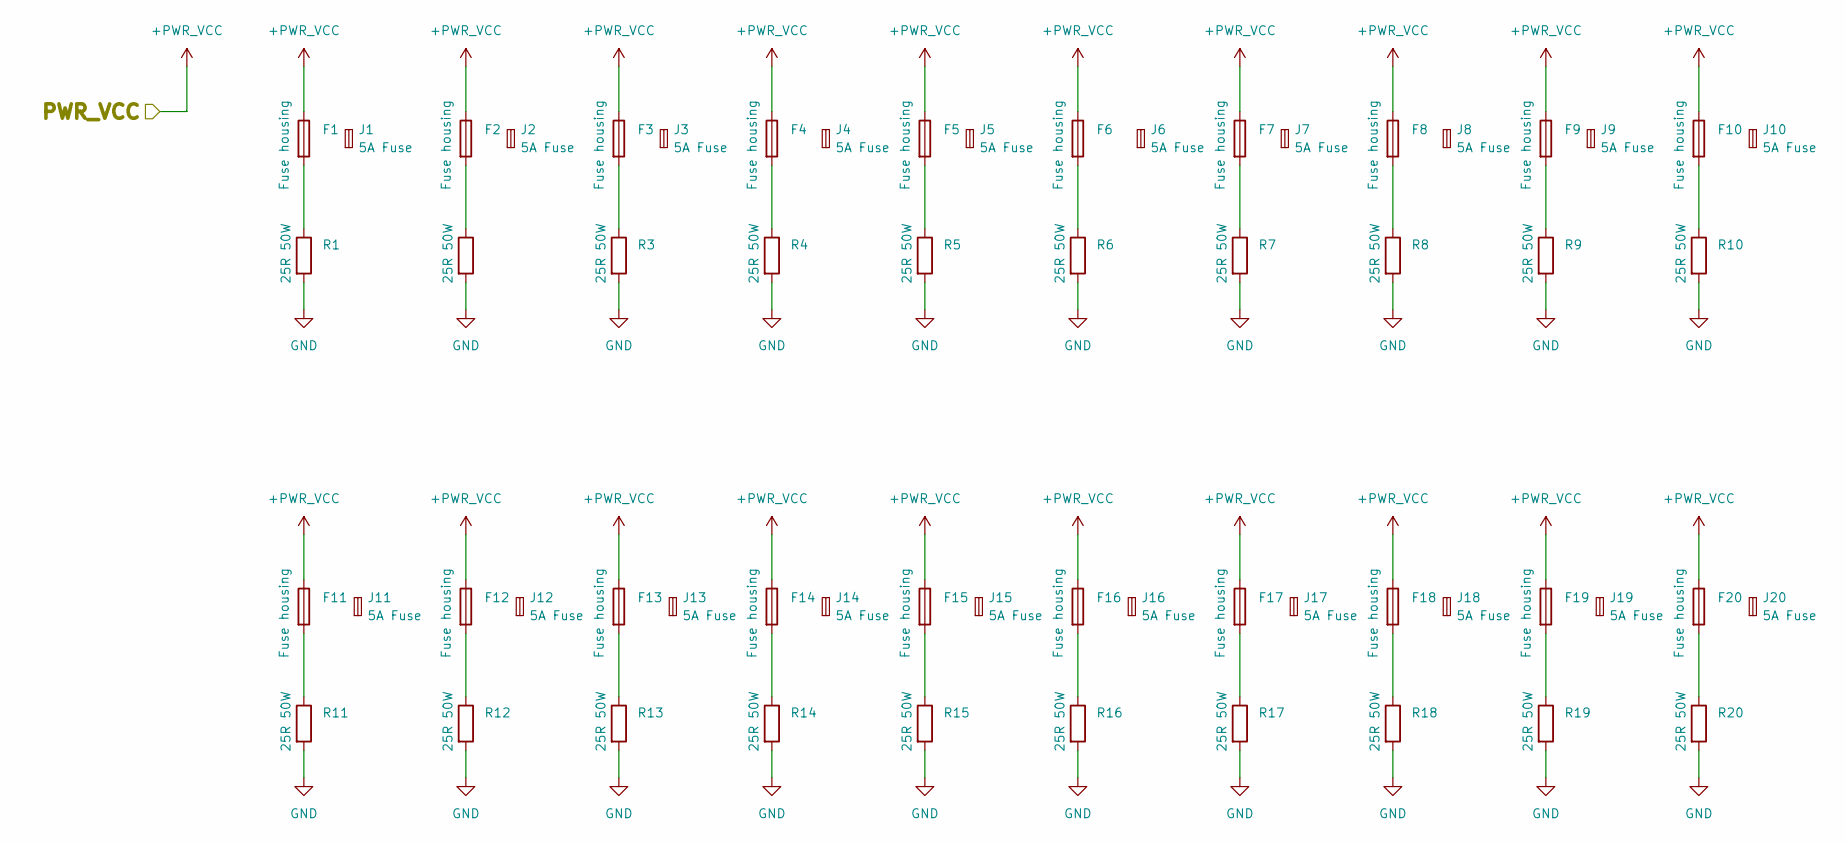
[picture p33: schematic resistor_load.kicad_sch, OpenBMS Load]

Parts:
F1, F2, F3, F4, F5, F6, F7, F8, F9, F10, F11, F12, F13, F14, F15, F16, F17, F18, F19, F20: Fuse housing; 3568; Manufacturer_Part_Number 3568
J1, J2, J3, J4, J5, J6, J7, J8, J9, J10, J11, J12, J13, J14, J15, J16, J17, J18, J19, J20: 5A Fuse; 0297005.WXNV; Manufacturer_Part_Number 0297005.WXNV
R1, R2, R3, R4, R5, R6, R7, R8, R9, R10, R11, R12, R13, R14, R15, R16, R17, R18, R19, R20: 25R 50W; L50J25RE; Manufacturer_Part_Number L50J25RE

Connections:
+PWR_VCC: F1.1, F2.1, F3.1, F4.1, F5.1, F6.1, F7.1, F8.1, F9.1, F10.1, F11.1, F12.1, F13.1, F14.1, F15.1, F16.1, F17.1, F18.1, F19.1, F20.1; also elsewhere on the board
GND: R1.2, R2.2, R3.2, R4.2, R5.2, R6.2, R7.2, R8.2, R9.2, R10.2, R11.2, R12.2, R13.2, R14.2, R15.2, R16.2, R17.2, R18.2, R19.2, R20.2; also elsewhere on the board
unnamed: F1.2, R1.1
unnamed: F2.2, R2.1
unnamed: F3.2, R3.1
unnamed: F4.2, R4.1
unnamed: F5.2, R5.1
unnamed: F6.2, R6.1
unnamed: F7.2, R7.1
unnamed: F8.2, R8.1
unnamed: F9.2, R9.1
unnamed: F10.2, R10.1
unnamed: F11.2, R11.1
unnamed: F12.2, R12.1
unnamed: F13.2, R13.1
unnamed: F14.2, R14.1
unnamed: F15.2, R15.1
unnamed: F16.2, R16.1
unnamed: F17.2, R17.1
unnamed: F18.2, R18.1
unnamed: F19.2, R19.1
unnamed: F20.2, R20.1

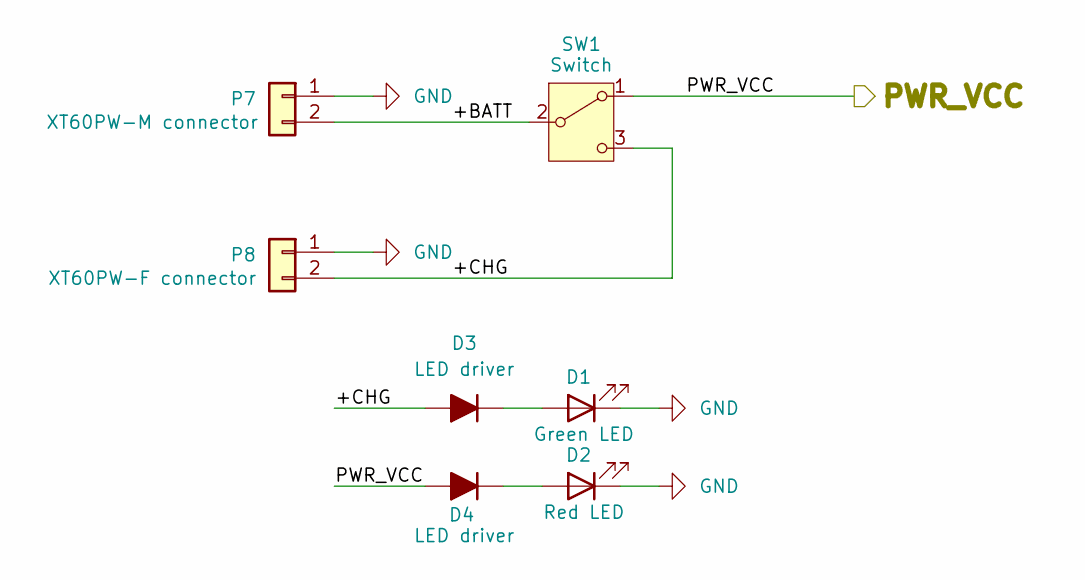
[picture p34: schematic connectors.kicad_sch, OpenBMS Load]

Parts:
D1: Green LED; LED_0603_1608Metric; Manufacturer_Part_Number LTST-S270KGKT
D2: Red LED; LED_0603_1608Metric; Manufacturer_Part_Number LTST-C190KRKT
D3, D4: LED driver; AL5809-15P1-7; Manufacturer_Part_Number AL5809-15P1-7
P7: XT60PW-M connector; AMASS_XT60PW-M_1x02_P7.20mm_Horizontal; Manufacturer_Part_Number XT60PW-M
P8: XT60PW-F connector; AMASS_XT60PW-F_1x02_P7.20mm_Horizontal; Manufacturer_Part_Number XT60PW-F
SW1: Switch; VRS-3-Q3PSI-19KNN-0-M2; Manufacturer_Part_Number VRS-3-Q3PSI-19KNN-0-M2

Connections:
+PWR_VCC: D4.2 (A), SW1.1 (A); also elsewhere on the board
/connectors/+BATT: P7.2, SW1.2 (B)
/connectors/+CHG: D3.2 (A), P8.2, SW1.3 (C)
GND: D1.1 (K), D2.1 (K), P7.1, P8.1; also elsewhere on the board
unnamed: D1.2 (A), D3.1 (K)
unnamed: D2.2 (A), D4.1 (K)

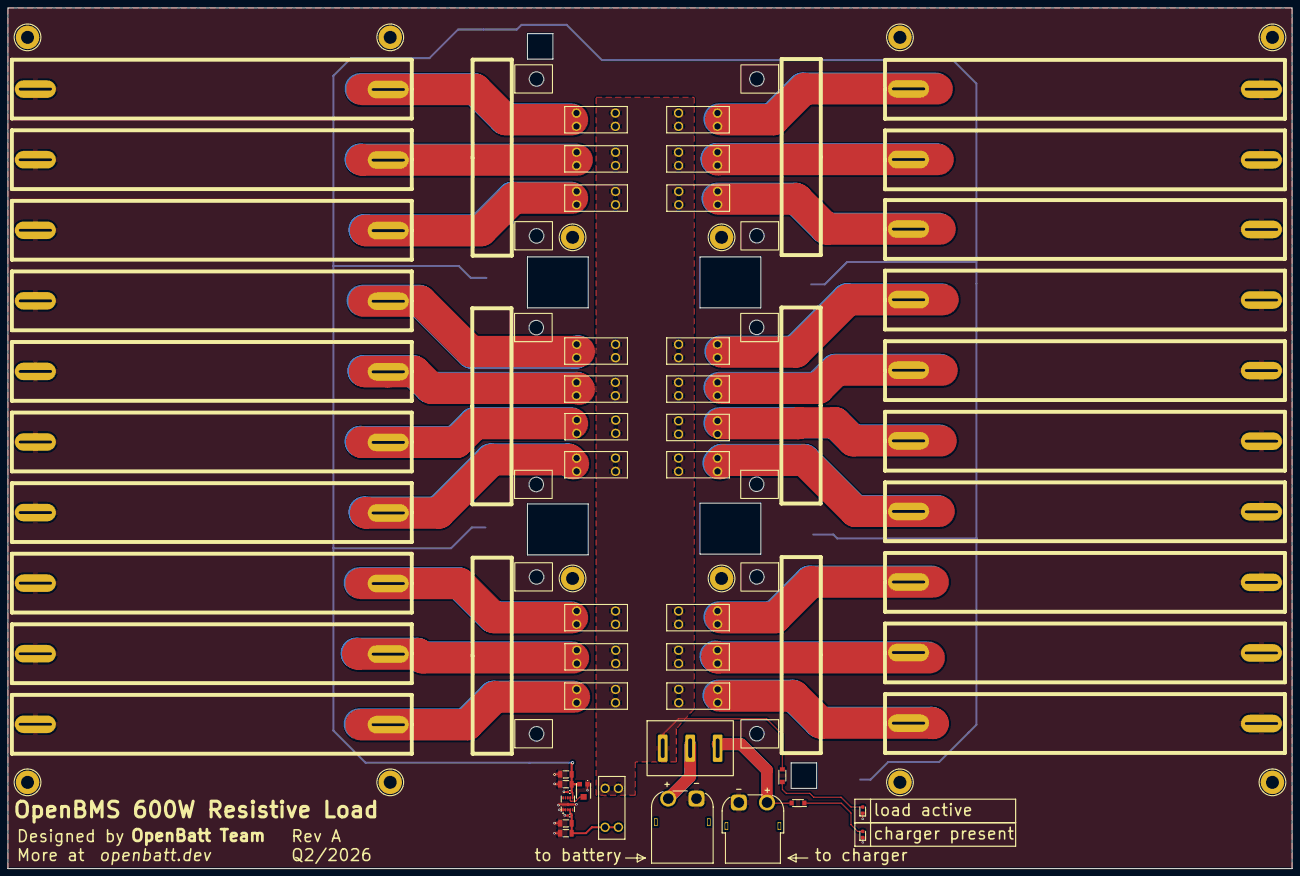
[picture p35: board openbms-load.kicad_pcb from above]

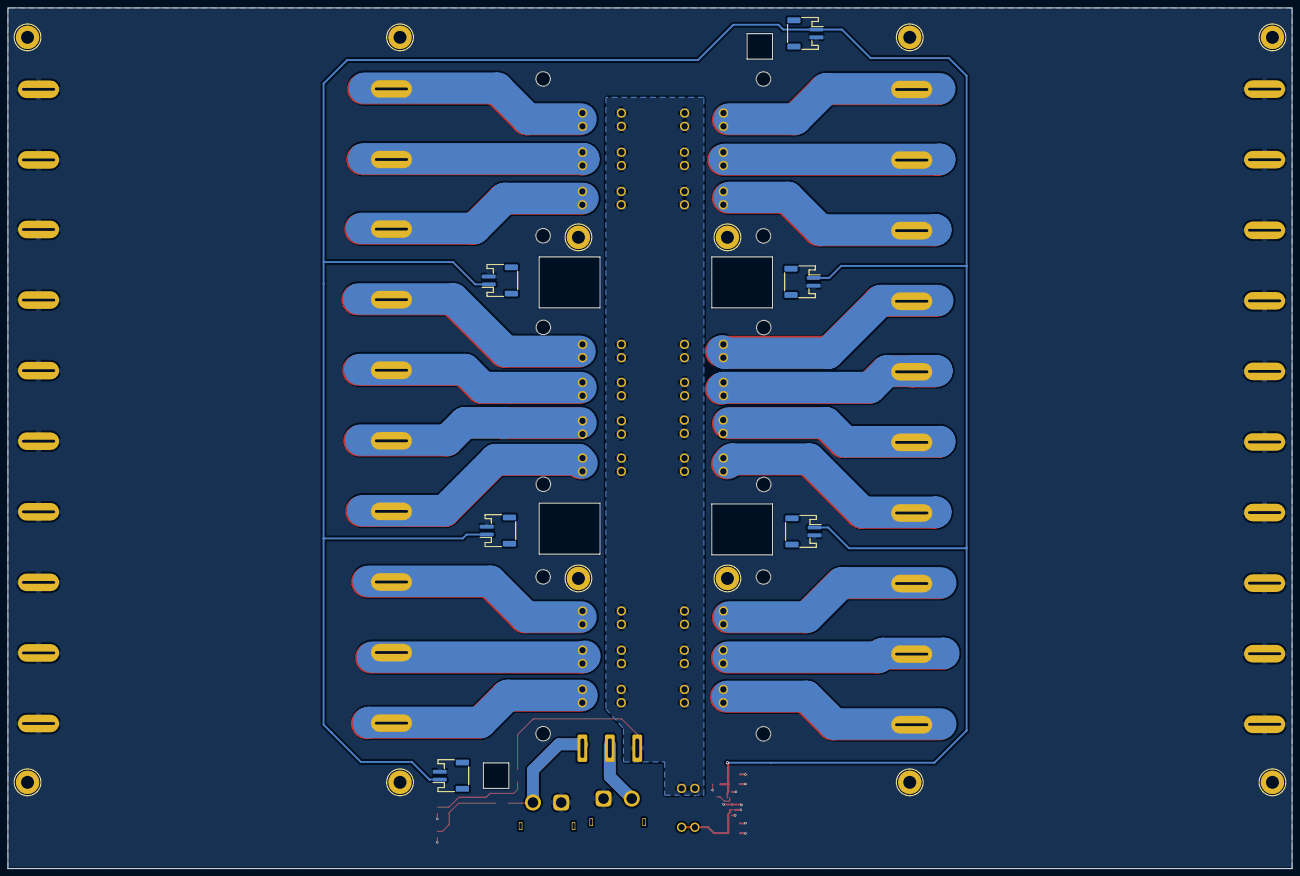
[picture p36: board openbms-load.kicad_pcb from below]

Board: 2 copper layers, 327.5 x 219.5 mm, 113 parts (18 on the bottom side), 29 nets.

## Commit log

2026-04-16 Initial commit, schematic and PCB layout Rev A release
    [0297005.WXNV.stp, 3568.stp, 633.stp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]
2026-04-17 Images added, schematic PDF created
2026-04-17 PCB label updated, project images added
    [openbms-load.kicad_pcb]
2026-04-17 Schematic description updated
    [openbms-load.kicad_sch]
2026-04-21 Production files release
    [openbms-load-B_Cu.gbr, openbms-load-B_Mask.gbr, openbms-load-B_Paste.gbr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]

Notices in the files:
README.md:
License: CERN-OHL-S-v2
